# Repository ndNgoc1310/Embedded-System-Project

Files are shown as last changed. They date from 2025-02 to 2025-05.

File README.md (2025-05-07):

# ChronoSync – Embedded Digital Clock

**Course**: EE3427 Embedded Systems  
**Semester**: 242  
**University**: Ho Chi Minh City University of Technology  
**Group**: TT01 – Group 01  
**Members**: Nguyễn Duy Ngọc, Bùi Đình Trung Nam, Nguyễn Hùng Minh

---

## 📌 Overview

ChronoSync is a compact, low-power embedded digital clock system built on the STM32F103C8T6 microcontroller. It features:

- Real-time timekeeping with ±2 ppm accuracy (DS3231)
- E-Ink display for ultra-low power static UI
- Alarm scheduling (up to 10 configurable alarms)
- Button-based and Bluetooth-based configuration
- Mobile app interface built with MIT App Inventor
- Persistent EEPROM-based alarm storage

---

## 🧩 Project Objectives

- Integrate real-time hardware modules using I²C, SPI, UART
- Optimize for low-power and battery-operated design
- Provide physical and mobile-based time/alarm configuration
- Ensure modular firmware and maintainability
- Design a compact PCB with future 3D enclosure support

---

## ⚙️ System Features

### ✅ Implemented

- Real-time clock display and update every second
- Time and alarm configuration via 5 physical buttons
- View and edit alarm slots with ON/OFF toggle
- Bluetooth mobile app for time and alarm setting
- Alarm match detection and buzzer melody
- Power-efficient E-Ink display
- EEPROM alarm persistence across resets
- System option to clear all alarms

### 🚧 Pending/Partially Implemented

- Button long-press for continuous input adjustment
- Factory reset, display test mode
- Battery holder integration and battery percentage
- Real-time update and editing from mobile app
- Final enclosure (currently carton prototype)
- Display UI refinement

---

## 📐 Hardware Overview

| Component | Description |
|---|---|
| **MCU** | STM32F103C8T6 (ARM Cortex-M3, 72 MHz) |
| **RTC** | DS3231SN – I²C, high-precision timekeeping |
| **Display** | 2.9” Waveshare E-Ink display – SPI |
| **EEPROM** | AT24C64D – 64Kbit, I²C |
| **Bluetooth** | HC-05 module – UART |
| **Buttons** | 5 tactile buttons – short & long press detection  |
| **Buzzer** | 9x4.2mm, 80 dB with transistor driver |
| **Power** | Buck converter TPS54231 + AMS1117-3.3V regulator  |

---

## 📱 Mobile App

- Developed using **MIT App Inventor**
- Connects via **Bluetooth HC-05**
- Supports:
  - Time sync & setup
  - Alarm configuration (DoW or DoM modes)
  - Real-time communication with STM32

---

## 🛠️ Development Tools

- **Hardware**: Altium Designer, Oscilloscope, Multimeter
- **Firmware**: STM32CubeIDE, STM32CubeMX, ST-Link Utility
- **App**: MIT App Inventor
- **Version Control**: GitHub

---

## 📈 Performance Highlights

| Constraint | Status  | Description |
|---|---|---|
| C-1.1 ±3 ppm Accuracy| ✅ Met | DS3231 TCXO verified over 24 hrs |
| C-2.1 Data Retention | ✅ Met | EEPROM retains data post power-loss  |
| C-3.1 Input <30 ms | ✅ Met | Short press detected ~20–30 ms |
| C-5.1 Size ≤ 15x15x8cm| ✅ Met  | PCB and layout within limits |

*See report for unverified constraints.*

---

## 📁 Folder Structure

```bash
.
├── 1. Documents/                 # Figures, planning documents, technical references
├── 2. Hardware Design/           # Schematic and PCB layout files (Altium Designer project)
├── 3. Firmware Design/           # STM32CubeIDE project for embedded firmware
├── 4. Mobile Application Design/ # MIT App Inventor source files and exported .aia/.apk packages
├── 5. Report                     # # Final formatted report for submission, figures, and exported PDF
├── .vscode/                      # VSCode workspace settings
├── README.md                     # Project overview and documentation

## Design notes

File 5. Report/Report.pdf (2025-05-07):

VIETNAM NATIONAL UNIVERSITY – HO CHI MINH CITY

UNIVERSITY OF TECHNOLOGY

----o0o---

# PROJECT REPORT

## TOPIC:

# CHRONOSYNC –

# EMBEDDED DIGITAL CLOCK

Subject: | Embedded System
Subject code: | EE3427
Instructor: | MSc. Bui Quoc Bao
Semester: | 242
Class: | TT01
Group: | 01
Group’s member: Nguyễn Duy Ngọc | 2251036
Bùi Đình Trung Nam | 2251032
Nguyễn Hùng Minh | 2251030

Ho Chi Minh City, May 2025

### TASK TABLE

Name | ID | Task name | Contribution | Rating
Nguyễn Duy Ngọc | 2251036 | Firmware Design | 100% | Good
Bùi Đình Trung Nam | 2251032 | Mobile Application Design | 100% | Good
Nguyễn Hùng Minh | 2251030 | Hardware Design Firmware Design (E-Ink Display handler) | 100% | Good

### TABLE OF CONTENTS

A. INTRODUCTION

### 1. Background and Motivation

Embedded systems play a crucial role in modern digital devices, from consumer electronics to industrial automation. Among these applications, digital clocks represent a fundamental yet essential embedded system that requires precise timekeeping, efficient hardware-software interaction, and user-centric interface design. The development of such a system provides an excellent opportunity to explore real-world applications of microcontroller programming, peripheral interfacing, and power optimization.

The ChronoSync project was initiated as a comprehensive learning experience to integrate multiple aspects of embedded system design into a cohesive, functional product. The motivation behind this project is threefold:

- Practical Application of Embedded Knowledge: By designing a digital clock from scratch, the team is able to apply theoretical knowledge gained from coursework—including real-time constraints, interrupt-driven programming, and low-power techniques—into a tangible product.
- Exploration of Component-Level Integration: The project encourages hands-on experience with various hardware modules such as E-Ink displays, real-time clocks (DS3231SN), non-volatile memory (AT24C64D EEPROM), and Bluetooth modules (HC-05). This integration broadens the team's exposure to widely used industry components and communication protocols like I²C, SPI, and UART.
- Focus on Usability and Expandability: The inclusion of a mobile app interface using MIT App Inventor reflects the team’s emphasis on enhancing user interaction and accessibility. This wireless control interface allows users to configure alarms and time settings remotely, simulating real-world smart device functionality.

Through this project, the team not only aims to build a reliable embedded digital clock system, but also to gain a deeper understanding of multidisciplinary embedded design— ranging from circuit design and firmware development to user experience (UX) and mobile connectivity.

### 2. Project Objectives

The objective of this project is to design and implement a compact, low-power digital clock system – ChronoSync – based on the STM32F103C8T6 microcontroller. To achieve this, the project is divided into the following structured tasks:

- Task 1: Component Analysis and Communication Integration: Study the operating principles and technical specifications of key modules, including the E-Ink display, HC-05 Bluetooth module, DS3231SN real-time clock (RTC), AT24C64D EEPROM, and the STM32F103C8T6 microcontroller. Emphasis is placed on integrating these components using I²C, SPI, and UART protocols to ensure reliable communication between peripherals and the MCU.

- Task 2: Power Supply Design and Energy Management: Analyze the operation of boost converters and low-dropout regulators (LDOs) to design an efficient power supply. Explore strategies for reducing power consumption. Select appropriate components and calculate electrical parameters to ensure stability, safety, and long battery life.
- Task 3: Hardware Design and Enclosure Development: Design the complete schematic and PCB layout using Altium Designer, integrating all functional blocks such as the MCU, display, memory, and input interface. Fabricate the PCB and develop a custom 3D-printed enclosure that matches the board dimensions, protects components, and enhances usability and aesthetics.
- Task 4: System Integration and Functional Testing: Combine the hardware and firmware subsystems into a fully functional prototype. Perform iterative testing to validate feature operation, resolve integration issues, and ensure overall system stability under various conditions.
- Task 5: Performance Evaluation and Refinement: Evaluate the system in terms of timing accuracy, responsiveness, power efficiency, and user interface usability. Compare the results with the original specifications, identify limitations, and propose improvements or extensions for future development.
- Task 6: Mobile Application Development: Design and implement a companion mobile application using MIT App Inventor. The app communicates with the embedded system via Bluetooth, allowing users to configure time, set alarms, and send control commands wirelessly, thereby enhancing accessibility and interaction.

This comprehensive project not only demonstrates core embedded systems principles, but also highlights cross-platform integration, real-time processing, and power-aware design in a complete, user-friendly product.

### 3. System Specifications 3.1. Functional Requirements

FR-1: The system must have time display functionality.

- FR-1.1: The system shall display the current time.
- FR-1.2: The system shall update the displayed time once every second.
- FR-1.3: The displayed format shall include hour, minute, day of week (DoW), date of month (DoM), month, and year in the format HH:MM, DD:MM:YY.
- FR-1.4: The system shall retain real-time data across power loss.

FR-2: The system must be able to store alarms.

- FR-2.1: The system shall allow users to configure up to 10 alarms.
- FR-2.2: Each alarm shall consist of: hour, minute, second, DoW or DoM, alarm mode (DoW/DoM/unused), and an ON/OFF flag.

- FR-2.3: The system shall compare current time and stored alarms every second to detect matches.
- FR-2.4: Upon matching, the system shall activate a buzzer and show the alarm status on screen.
- FR-2.5: Alarm configurations shall be retained across power cycles.

FR-3: The system must allow time and alarm configuration via physical buttons.

- FR-3.1: The buttons shall support incrementing, decrementing, and navigating between configuration fields.
- FR-3.2: The system shall support both short press and long press detection to accelerate user input.

FR-4: The system must allow alarm review and editing.

- FR-4.1: The system shall allow users to browse existing alarms by slot index.
- FR-4.2: The system shall allow users to toggle an alarm’s ON/OFF state while reviewing.
- FR-4.3: The system shall support editing a selected alarm.

FR-5: The system must allow time and alarm configuration wirelessly.

- FR-5.1: The system shall support a mobile application for wireless configuration.
- FR-5.2: The system shall communicate with the app via bluetooth.
- FR-5.3: The app shall support time synchronization and alarm setup from a smartphone.

FR-6: The system shall provide system additional features.

- FR-6.1: System Options shall include:
- FR-6.1.1: Clear all alarms.
- FR-6.1.2: Perform factory reset.
- FR-6.1.3: Run display test pattern.
- FR-6.1.4: Show distributor information.

FR-7: The device must be compact, portable, and physically robust.

- FR-7.1: The device shall have a case made of Mica or ABS plastic for lightweight and durable protection.

FR-8: The device must support low power consumption and extended battery operation.

- FR-8.1: The device shall include an E-Ink display to minimize power consumption.
- FR-8.2: The device shall be powered by a rechargeable lithium-ion battery to support long-duration operation.
- FR-8.3: The system shall display the remaining battery level in percentage on the screen.

### 3.2. Constraints and Performance Requirements

C-1: Timing and Accuracy

- C-1.1: The system shall ensure time deviation is less than ±3 ppm at room temperature.
- C-1.2: Alarm matching logic shall be executed within 50 ms per main loop iteration.
- C-1.3: On power loss, the system shall maintain accurate real time for at least 30 days.

C-2: Alarm Storage

- C-2.1: The system must retain all alarm data across power loss.
- C-2.2: Total memory usage for alarm storage shall not exceed 50 bytes.
- C-2.3: Storage read/write operations shall complete in less than 10 ms.

C-3: Input Responsiveness

- C-3.1: A short button press shall be detected with latency under 30 ms.
- C-3.2: A long button press shall be registered after holding the button for 600 ms.
- C-3.3: Button debouncing shall ensure fewer than 1 false trigger per 100 presses.

C-4: Power and Energy Constraints

- C-4.1: The system shall operate on four 2000 mAh, 3V lithium-ion batteries.
- C-4.2: The system shall function for at least 90 days on a full charge in idle conditions.
- C-4.3: The system shall consume less than 3 mW during typical operation.
- C-4.3.1: The system shall perform periodic operations (e.g., real-time updates, alarm checks, battery polling) once per second to minimize power usage.
- C-4.3.2: The display shall consume no more than 0.02 mW in all operating modes.
- C-4.3.2.1: The display refresh rate shall be limited to 1 Hz when displaying real time, and shall only refresh on value changes in other modes.

C-5: Physical Dimensions

- C-5.1: The overall device dimensions shall not exceed 15 cm × 15 cm × 8 cm.
- C-5.2: The total weight of the device shall be less than 300 g.

B. MATERIALS AND METHODS

### 1. List of components

No. | Component | Quantity | Function
1 | DC5521 Power Jack 1A | 1 | Standard DC input for external power supply or charger.
2 | SS54 Schottky Diode 5A 40V | 1 | Drops the input voltage before the inductor in the buck converter.
3 | SMD CDRH127 Inductor 68µH 3.2A | 1 | Enables current regulation and energy storage in the buck converter circuit.
4 | TPS54231DR Buck Converter | 1 | Steps down 12V input to lower voltages (5V) efficiently for system operation.
5 | AMS1117 Regulator 3.3V 1A | 1 | Provides a stable 3.3V output from the 5V rail to power the STM32 and other 3.3V devices.
6 | SMD Capacitor 100µF | 4 | Used for power decoupling and smoothing voltage across supply rails.
7 | TAJC476K016RNJ 2312 Tantalum Capacitor 47uF | 2 | Acts as a local bypass capacitor to stabilize voltage and reduce noise near sensitive ICs.
8 | STM32F103C8T6 Microcontroller | 1 | Main controller managing timekeeping, UI, display, and communication.
9 | SMD HC49-S Crystal Oscillator 8MHz | 1 | Provides system clock for STM32 core.
10 | FC-135 3215 Crystal 32.768kHz | 1 | Provides a low-frequency clock source option for the STM32 core.
11 | DS3231SN RTC Module | 1 | High-accuracy real-time clock with backup capability.
12 | AT24C64D-SSHM-T EEPROM 64Kbit | 1 | Stores alarm settings and user configuration permanently.
13 | Tactile Buttons 12 x 12 mm | 5 | Buttons for user input, each with short/long press detection.
14 | SMD 0805 Resistor 10kΩ | 5 | Pull-up/down resistors for buttons and logic-level conditioning.
15 | SMD 0805 Capacitor 100nF | 5 | Used for hardware debouncing of push buttons by filtering out signal noise and eliminating false triggers.
16 | Waveshare E-Ink Display 2.9" | 1 | Low-power, high-contrast display for time and status.
17 | SMD 0805 LED | 3 | Status indicators for 5V rail, 3.3V rail, and the PC13 GPIO pin.
18 | 9056-TS Buzzer 80dB | 1 | Emits sound when an alarm is triggered.
19 | MMBT2222A NPN Transistor 40V 0.6A | 1 | Used as a low-side switch to drive current to the buzzer.

20 | HC-05 Bluetooth Module | 1 | Enables wireless setup and control via smartphone app.
21 | 2-Pin Female XH2.54 Cable | 5 | Used to easily connect buttons to the PCB.
22 | 2-Pin Male Header XH2.54 | 5 | Mates with XH2.54 cables to provide sturdy, pluggable connections for signals on the PCB.
23 | 8-Pin Male Header XH2.54 | 1 | Used for display signal interfaces (SPI).
24 | 8-Pin Female XH2.54 Cable | 1 | Paired with XH2.54 headers for SPI interface.

### 2. Selection Criteria and Justifications

The components selected for the ChronoSync embedded digital clock were chosen based on critical engineering criteria: functional reliability, power efficiency, cost-effectiveness, compactness, and ease of integration. Each category below outlines the rationale for component selection in terms of system requirements and performance optimization.

### 2.1. Microcontroller Unit (MCU)

Component: STM32F103C8T6 (ARM Cortex-M3, 72MHz)

Justification:

- Offers sufficient computational power to handle real-time clock tracking, alarm scheduling, display control, and Bluetooth communication.
- Provides a wide range of peripheral interfaces: I²C (RTC, EEPROM), SPI (E-Ink), UART (Bluetooth).
- Low power consumption and supported by STM32CubeIDE and HAL drivers for efficient firmware development.

### 2.2. Power Supply

Components: TPS54231 Buck Converter, AMS1117-3.3V Regulator, SS54 Schottky Diode, CDRH127 Inductor, 100µF Electrolytic Capacitors, TAJC476K016RNJ 47µF Tantalum Capacitors

Justification:

- TPS54231 is a high-efficiency step-down converter capable of supplying 2A output current, ideal for converting 12V DC input to 5V with minimal power loss.
- AMS1117-3.3V linear regulator provides a stable 3.3V output necessary for core system components such as the STM32, RTC, EEPROM, and Bluetooth module.
- The SS54 Schottky diode ensures low forward voltage drop and fast switching, improving conversion efficiency and protecting against reverse current.

- The SMD CDRH127 inductor (68µH, 3.2A) stabilizes current flow through the buck converter, reducing voltage ripple and electromagnetic interference.
- Electrolytic and ceramic SMD capacitors are placed on power lines to suppress voltage spikes, smooth output, and reduce noise coupling.
- TAJC476K016RNJ Tantalum capacitors (47µF) act as bypass and filtering elements, ensuring voltage stability during transient loads and providing local energy storage near the regulators.

### 2.3. Oscillators and Timing Components

Component: 8MHz Crystal (STM32 system clock), 32.768kHz FC-135 Crystal (RTC backup)

Justification:

- 8MHz crystal ensures stable and accurate operation of the STM32 MCU.
- 32.768kHz crystal enhances timekeeping accuracy and is compatible with low-power RTC operation.

### 2.4. Display System

Component: 2.9-inch Waveshare E-Ink Display

Justification:

- Power-efficient as it only draws current during screen refresh.
- Excellent visibility in ambient light; ideal for static time display.
- Communicates over SPI with STM32, reducing pin usage and enabling fast updates.

### 2.5. Timekeeping

Component: DS3231SN RTC Module

Justification:

- Temperature-compensated crystal oscillator for ± 2 ppm accuracy.
- Maintains real-time across power cycles using coin-cell backup.
- Communicates over I²C with minimal code overhead.

### 2.6. Alarm Storage

Component: AT24C64D EEPROM (64Kbit)

Justification:

- Non-volatile memory ensures alarm data persists through power loss.
- Fast I²C communication with write cycles well within application constraints.

- 64 Kbit provides ample space for storing up to 10 alarm configurations, along with headroom for future feature upgrades or additional system data.

### 2.7. User Interface – Buttons and Indicators

Component: Tactile Push Buttons (12×12mm), SMD LED 0805 (Power Indicators), 100nF Capacitors, SMD 0805 Resistor 10kΩ

Justification:

- Buttons provide a reliable interface for configuration and navigation. Their size ensures usability.
- Dual short/long press recognition expands functionality without additional components.
- SMD LEDs provide visual feedback for system states (5V, 3.3V, heartbeat via PC13 pin).
- 100nF ceramic capacitors and 10 kΩ resistors are used for hardware debouncing of button signals.

### 2.8. Audio and Output Control

Components: 9x4.2mm 80dB Buzzer, MMBT2222A NPN Transistor

Justification:

- The buzzer provides audible feedback for alarm activation.
- The MMBT2222A acts as a current driver, switching the buzzer on/off through a GPIO pin safely without overloading the MCU.

### 2.9. Wireless Communication

Component: HC-05 Bluetooth Module

Justification:

- Enables wireless communication with a custom mobile app developed using MIT App Inventor.
- UART-based interface simplifies integration with STM32.
- Supports bidirectional control of time and alarms from mobile devices.

2.10.Connectors and Wiring

Component: XH2.54 Bus Cables (2-pin and 8-pin), XHB-2A Connectors

Justification:

- These connectors simplify module interconnection and allow easy debugging or module replacement.

- Standardized 2.54mm pitch ensures compatibility with PCB and peripheral modules.

### 3. Development Tools

The development of the ChronoSync embedded system leverages a comprehensive suite of software and hardware tools for circuit design, firmware development, simulation, and debugging. Each tool was selected based on compatibility with the STM32 platform, support for industry standards, and community resources.

### 3.1. Hardware Development Tools

- Altium Designer
- Purpose: Used for schematic capture and PCB layout design.
- Justification: Professional-grade EDA tool with precise control over routing, layout constraints, and multi-layer design, enabling high-reliability circuit boards suitable for compact embedded systems.
- Soldering Station & Solderer
- Purpose: Manual soldering of surface-mount and through-hole components.
- Justification: Required for assembling the custom-designed PCB, especially for SMD parts like STM32F103C8T6 and EEPROM.
- Digital Multimeter & Oscilloscope
- Purpose: Testing power lines, signal integrity, and time-domain behavior of waveforms (e.g., SPI, UART, PWM for buzzer).
- Justification: Essential for debugging hardware-level faults and verifying timing constraints.

### 3.2. Firmware and Embedded Software Tools

- STM32CubeIDE
- Purpose: Main integrated development environment (IDE) for writing, compiling, and debugging C code on the STM32 platform.
- Justification: Official STMicroelectronics toolchain supporting STM32F1 series with STM32CubeMX integration, HAL drivers, and peripheral configuration GUI.
- STM32CubeMX
- Purpose: Peripheral and clock configuration tool with automatic code generation.
- Justification: Simplifies hardware abstraction and generates consistent initialization code, reducing development errors.
- ST-Link Utility/OpenOCD
- Purpose: Flashing and debugging firmware via ST-Link.

- Justification: Enables low-level programming and real-time debugging with breakpoint and register inspection capability.

### 3.3. Mobile Interface Tools

- MIT App Inventor
- Purpose: Rapid development of the companion mobile app.
- Justification: Offers a block-based visual programming environment suitable for prototyping Bluetooth-based UI without deep Android development expertise.

### 3.4. Version Control and Documentation

- GitHub
- Purpose: Source code management, issue tracking, and collaboration.
- Justification: Facilitates transparent teamwork and history tracking. All
design | files, | firmware, | and | documents | are | hosted | at:
https://github.com/ndNgoc1310/Embedded-System-Project
- Microsoft Word
- Purpose: Report writing and formatting.
- Justification: Allows structured documentation of the development process and output files suitable for academic and professional submission.

### 4. Programming and Debugging Methodology 4.1. Programming Structure and Naming Convention

The firmware is developed using the C programming language, structured into modular units with clear separation between application logic and low-level hardware interaction. This is achieved through a multi-layered architecture, including:

- Application Layer: Handles system state logic and mode transitions.
- Middleware Layer: Manages data encoding/decoding, EEPROM access, and RTC time parsing.
- Driver Layer: Interfaces with external peripherals such as the RTC (DS3231), EEPROM (24C32), buttons, buzzer, and E-Ink display.

All functions and variables strictly follow a unified naming convention. Prefixes are assigned according to module ownership, ensuring clarity and preventing namespace collisions. This convention included:

- camelCase for local variables,
- lowercase_with_underscores for global variables and struct members,
- Upper_Camel_Snake_Case for function names, and
- ALL_CAPS_WITH_UNDERSCORES for macros and constants.

This structured organization and naming standard promote code readability, maintainability, and ease of collaboration among team members.

### 4.2. Debugging Strategy

A disciplined debugging approach was followed throughout development. Using STM32CubeIDE, the following techniques were employed:

- Live Expressions Monitoring: Temporary and persistent state variables were tracked in real time to understand logic flow and diagnose anomalies.
- Breakpoints and Step Execution: Specific sections of code were paused and stepped through to trace faults and validate assumptions.
- Hardware-in-the-Loop Testing: Each update was tested on real hardware to verify actual peripheral behavior and detect timing or synchronization issues not visible in simulation.
- Modular Testing: Subsystems (e.g., EEPROM access, time sync, buzzer logic) were individually validated before full integration.
This methodology ensured high firmware reliability, fast bug localization, and efficient conflict resolution across hardware and software boundaries.

C. SYSTEM DESIGN

### 1. System Architecture Overview

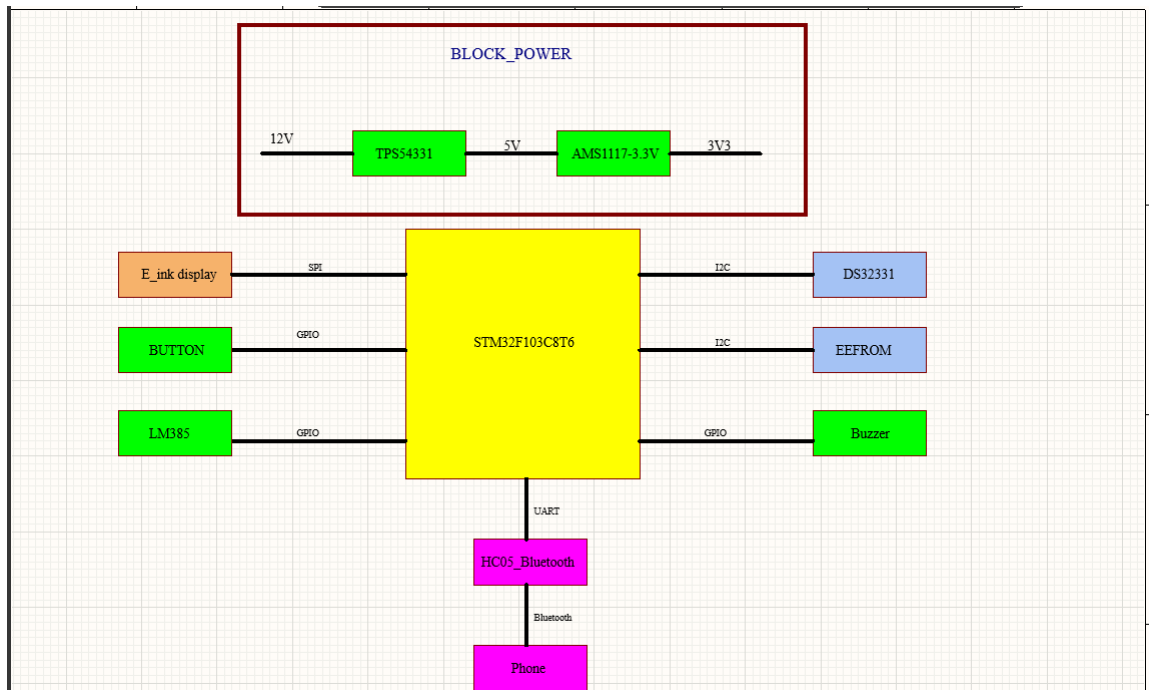
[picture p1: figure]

Figure 1. System overview
Phone
- Task: Communicate with the system via Bluetooth connection.
- Function: User interaction.

HC05 BLE (Bluetooth Low Energy)

- Task: Wireless connection with the phone via Bluetooth.
- Function:
- Receive signals from the phone (e.g., time adjustments).
- Transmit data to the STM32 microcontroller via UART.
- Bidirectional communication between the phone and MCU to update clock status or adjust time

IC TPS54331

- Task: Step down the voltage from 12V to 5V.
- Function: Step down the voltage to 5V to supply BLE and to step down 3V3 through the AMS1117.

IC AMS1117

- Task: Step down the voltage from 5V to 3.3V.
- Function: Supply voltage to STM32F103C8T6, E-ink-display and other devices.

STM32F103C8T6 Microcontroller

- Task: Control the entire system’s operation.

- Function:
- Process data received from the BLE module
- Control the E-Ink display to show time.
- Process the signal from the buttons.
- Read and write the data from the DS3231 and EEFROOM
- Manage power from the boost, buck converters, and backup battery. IC DS3231
- Task: Store the data of time.
- Function: Read and write the time data.

EEFROOM

- Task: Read and store data.
- Function: To store the data alarm.

IC LM385

- Task: The op amp to amplified the current.
- Function: Like the buffer to measure the voltage.

Buzzer

- Task: Generate audible alerts or notifications in response to specific events or conditions within the system.
- Function: Notify the alarm.

E-ink display.

- Task: Display the information for the users.
- Function: Display time and setting.

### 2. Hardware Design

a) Block diagram

Power supply

- In accordance with the design requirements, the product's power consumption should be minimized. Therefore, the team has decided to use the TPS54331 IC (buck DC converter) to step down the voltage to 5V, followed by the ASM1117 to further step down to 3.3V.
- Additionally, the power input will have two voltage sources: one from the adapter and another from the battery.

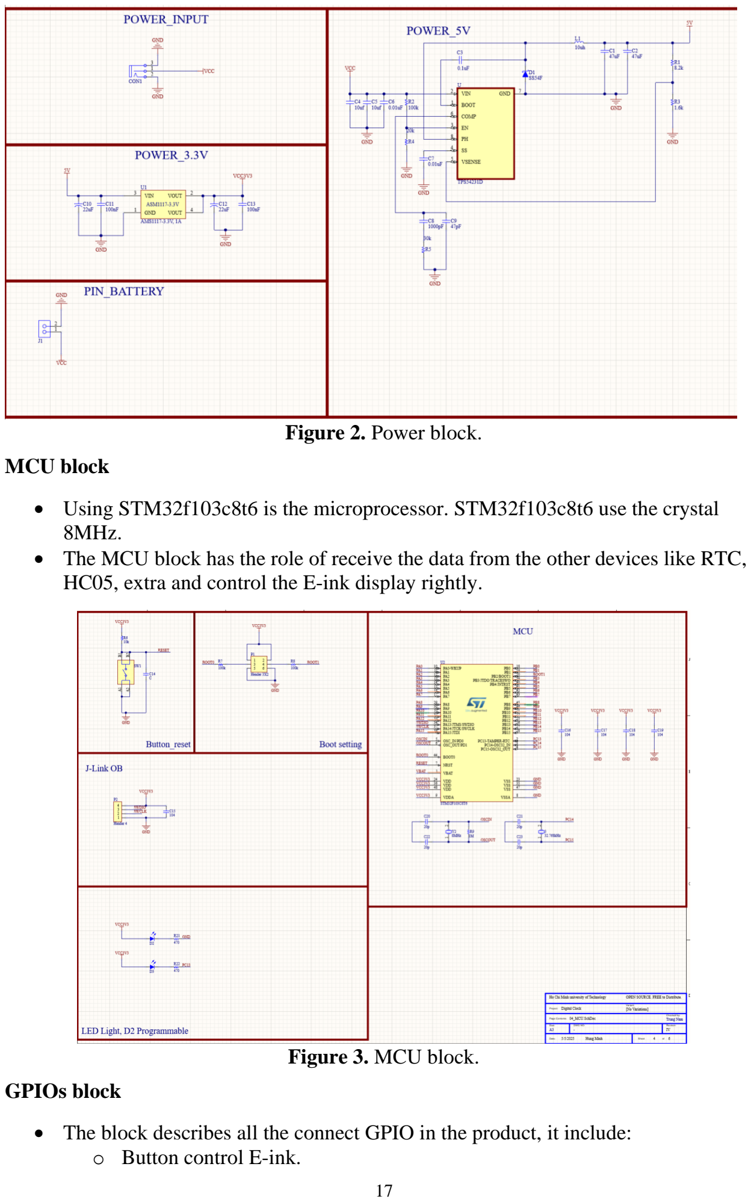
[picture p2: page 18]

Figure 2. Power block.

MCU block

- Using STM32f103c8t6 is the microprocessor. STM32f103c8t6 use the crystal 8MHz.
- The MCU block has the role of receive the data from the other devices like RTC, HC05, extra and control the E-ink display rightly.

Figure 3. MCU block.

GPIOs block

- The block describes all the connect GPIO in the product, it include:
- Button control E-ink.

- The IC LM385 to measure the Pin battery.
- The GPIO to control the buzzer.

Figure 4. GPIOs block.

Communication Protocols block

The block describes all the connect of protocol in the product:
- The EEFROM will be used by AT24C family and we will implement through the I2C. The same with RTC DS32331 is transferred the data through the I2C.
- The data of module HC-05 will be transmitted by UART while E-ink is used SPI protocol.

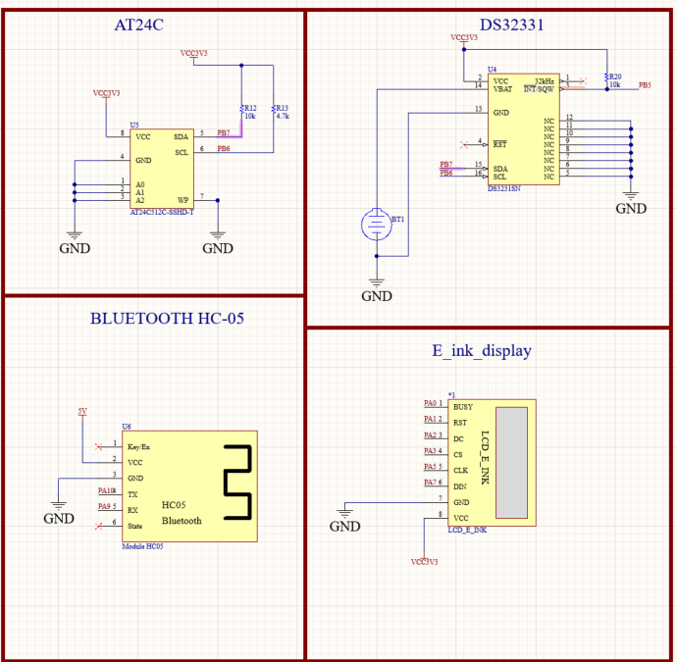
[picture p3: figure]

Figure 5. Communication Protocol block.

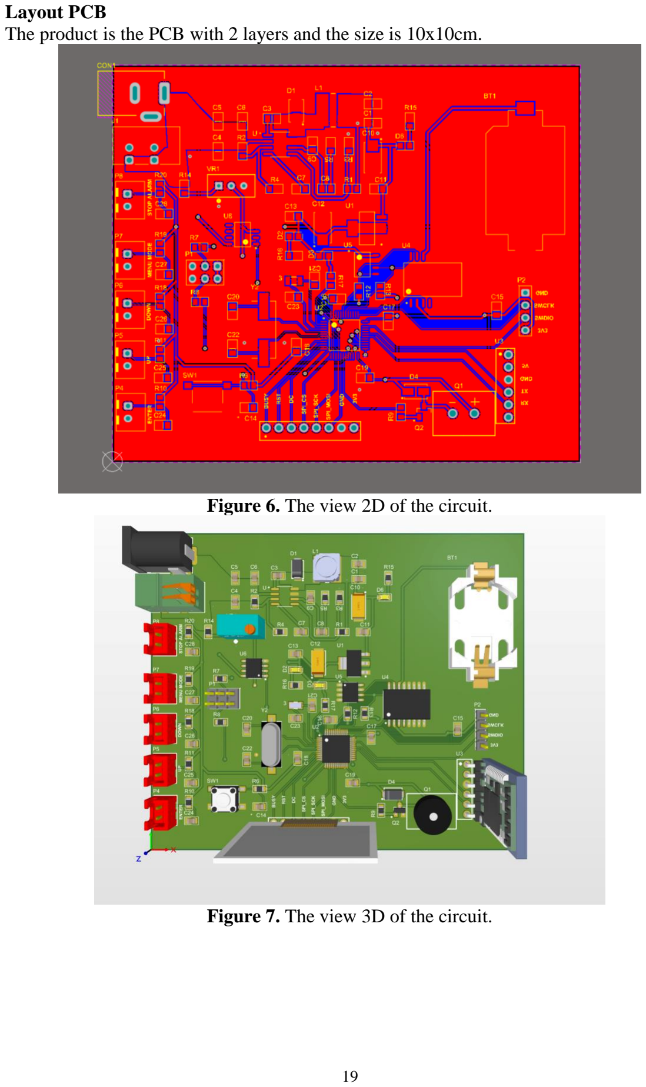
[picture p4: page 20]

Layout PCB
The product is the PCB with 2 layers and the size is 10x10cm.

Figure 6. The view 2D of the circuit.

Figure 7. The view 3D of the circuit.

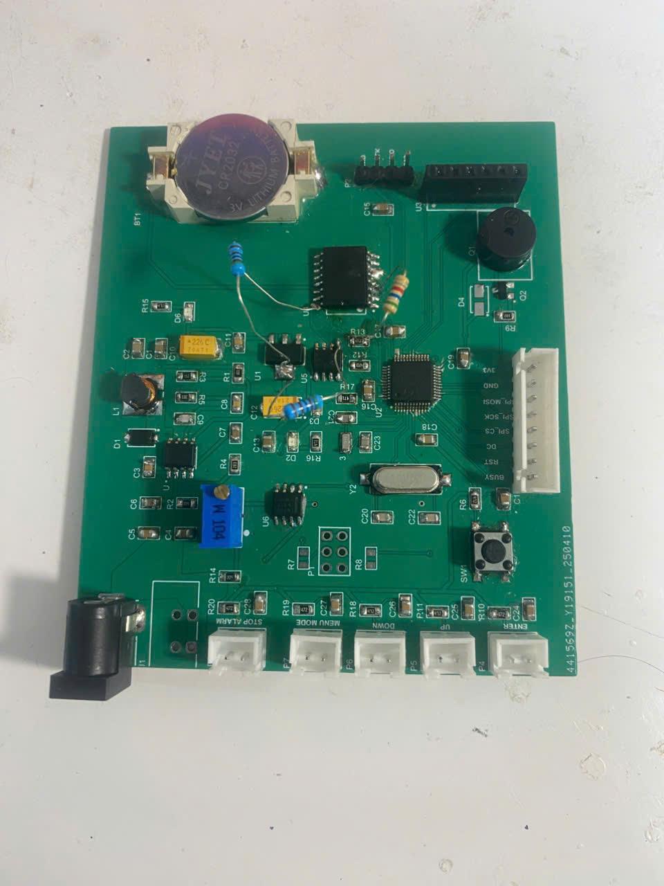
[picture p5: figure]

Figure 8. The view of the circuit.

### 3. Firmware Design

a) Requirement software
- Ability to process real-time signals ensuring the accuracy of real time.
- Users can adjust the time via Bluetooth: allowing users to easily adjust the time remotely.
- Can store time data when replacing the battery: limiting the need for users to adjust the time each time the battery is replaced.pin.
b) Flow chart:
- The flow chart will be divided into 3 parts:
- The first part is about the default mode. It will display the data read from the RTC and check the alarm.
- The second part is the flow chart of the system options choosing mode.
- The third part is the flow chart of controlling button.
- Default mode:

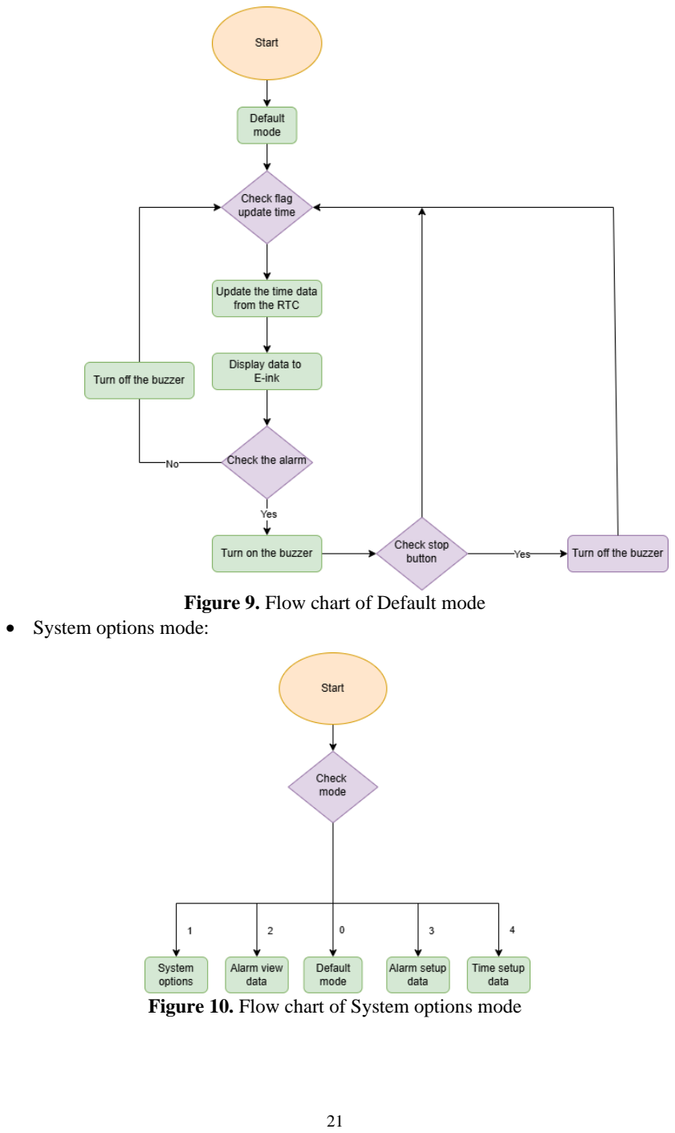
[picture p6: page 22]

Figure 9. Flow chart of Default mode
- System options mode:

Figure 10. Flow chart of System options mode

- Button setting:

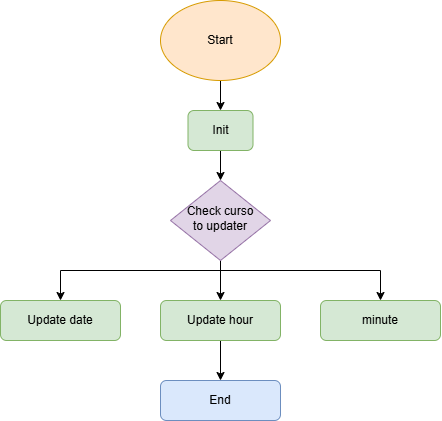
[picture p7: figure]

Figure 11. Flow chart of Button setting mode

### 4. Mobile Application Design

a) Introduction to MIT App Inventor
- To enhance user interaction and increase system flexibility, the ChronoSync embedded digital clock integrates a custom-built Android application developed using MIT App Inventor. This mobile app provides a wireless interface for adjusting both the time and alarms of the clock via Bluetooth communication, eliminating the need for manual configuration through physical buttons.
- The integration of the MIT App serves several important purposes in the system. Firstly, it improves user convenience, allowing real-time configuration of the clock from a distance without the need to physically access the hardware. Secondly, it enables multi-mode interaction, with distinct features such as time adjustment and flexible alarm scheduling for both weekly and monthly routines. Lastly, it demonstrates the practicality of combining embedded hardware with mobile software to build a more modern and responsive embedded system.
- Using MIT App Inventor brings notable advantages:
- Rapid development with a visual programming environment
- Cross-platform compatibility for Android devices
- Ease of integration with Bluetooth modules like HC-05
- User-friendly interface design without advanced coding

- In the ChronoSync project, the MIT App plays a crucial role as the primary interface between the user and the embedded clock system. It allows seamless communication over Bluetooth, enabling users to manage essential clock settings efficiently and intuitively.
b) User interface and modes

MIT App Inventor let user define the interface of the app and It’s functions through blocks.

Figure 11. Designer mode of MIT App Inventor

Figure 12. Blocks mode of MIT App Inventor Screen 1: Menu

Screen 1 is the first screen and the default screen that will automatically appear when we open the app. In this screen, we are free to choose what to do with our clock through 3 buttons:
- "Update Time and Date"
- "Update Alarms in Week"

- "Update Alarms in Month"

In Designer mode, we will see 3 buttons appear on the screen like the figure below:

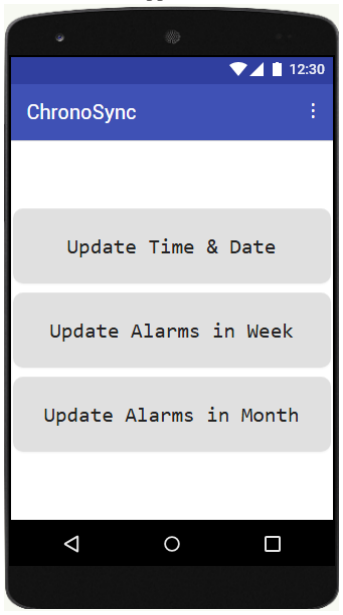
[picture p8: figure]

Figure 13. Screen 1
In the Blocks mode, We can observe the function of each buttons:

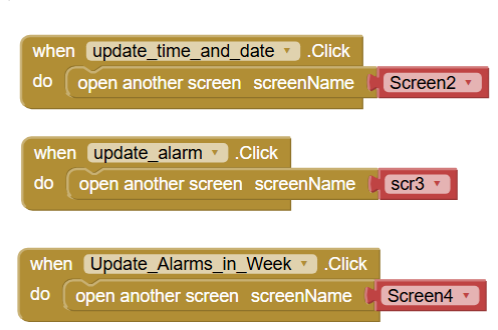
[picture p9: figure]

Figure 14. Blocks functions of Screen 1 For each buttons, they will lead us to others screen according to their functions. In this screen, the app is staying in Mode 0 (Idle Mode): Do nothing.

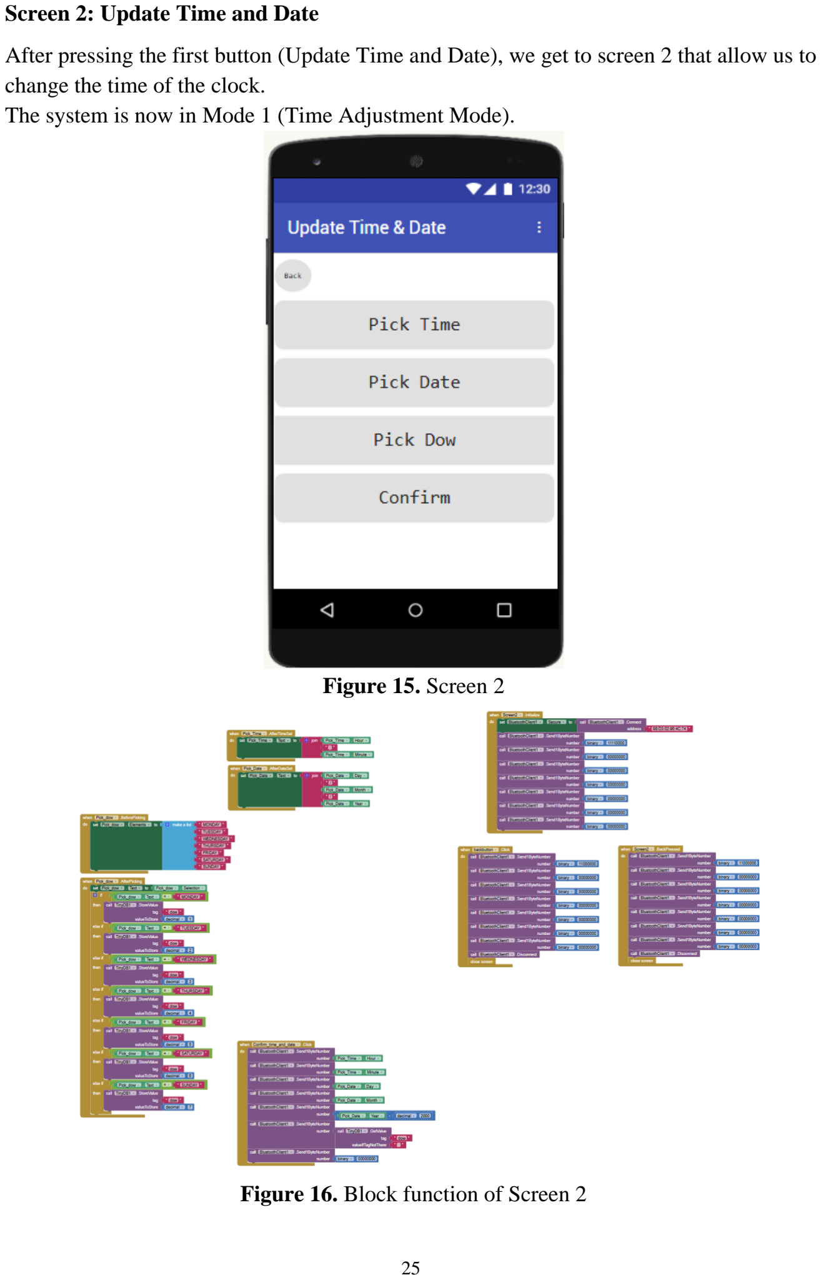
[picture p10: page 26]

Screen 2: Update Time and Date

After pressing the first button (Update Time and Date), we get to screen 2 that allow us to change the time of the clock.
The system is now in Mode 1 (Time Adjustment Mode).

Figure 15. Screen 2

Figure 16. Block function of Screen 2

In this mode, we can change time, date, day of the week and then press the confirm button to admit the adjustment to the clock.

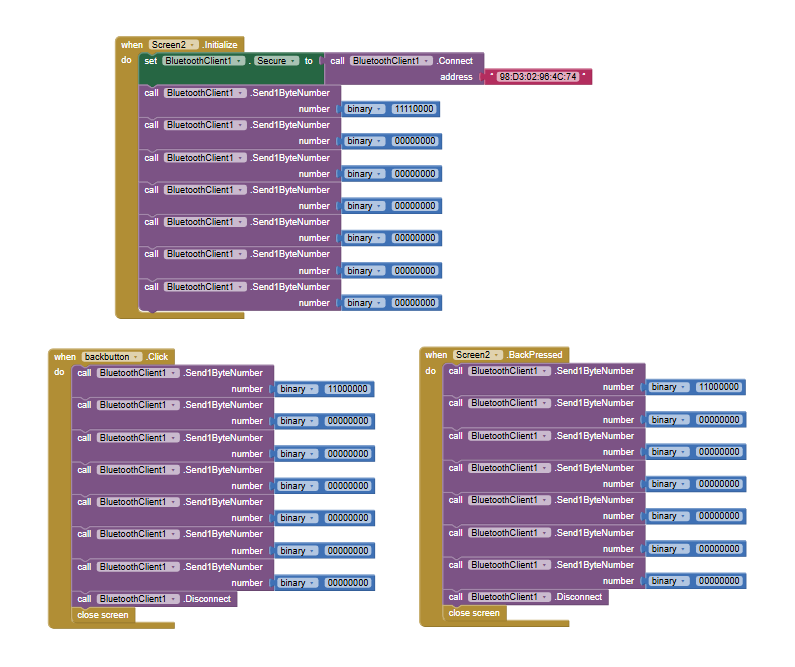
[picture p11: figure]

Figure 17. Initializing block and ending blocks of Screen 2 When the screen 2 initialize, the app will automatically connect to HC05 through address 98:D3:02:96:4C:74. After that, it will send 7 byte data (F0-00-00-00-00-00-00) to STM32 to announce that we’re in mode 1. The first byte is not only for hour data but for mode data too. Only when we press the back button or back press, STM32 will receive data (C0-00-00-00-00-00-00) that let it escape mode 1 to turn back to mode 0.

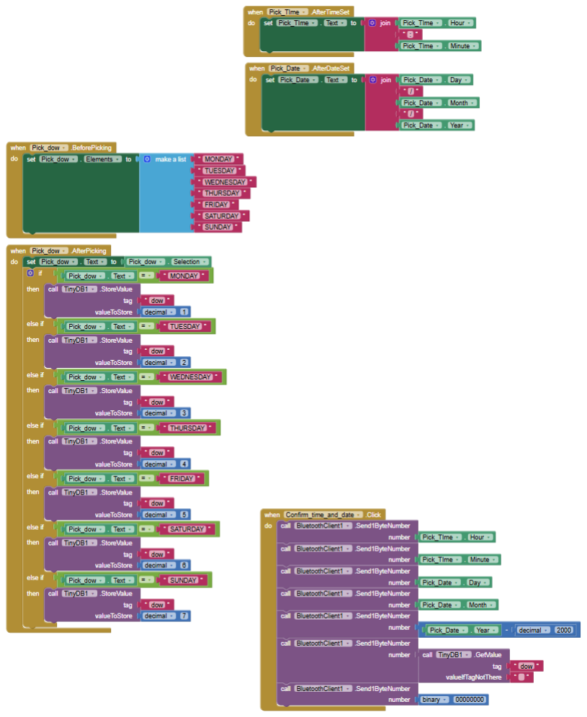
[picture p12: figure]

Figure 18. Function blocks of Screen 2 After set the time and date button, they will display the value that we chose.
For day of the week, we will choose from a list of day (Monday to Sunday). After picking, it will show our option on the screen and also save the value of dow value as it’s equivalent number. (1-Monday, 2-Tuesday, etc).
When we press the confirm button, all the data of time and date will be sent to STM32 via Bluetooth.
Note that data of the year have to minus for 2000 as it’s too big to fit in 1 byte.
Screen 3: Update Alarms in Month

After pressing the second button (Update Alarms in Month), we get to screen 3 that allow us to change the alarms of the clock in date mode.
The system is now in Mode 2 (Alarms Adjustment Mode).

Figure 19. Screen 3

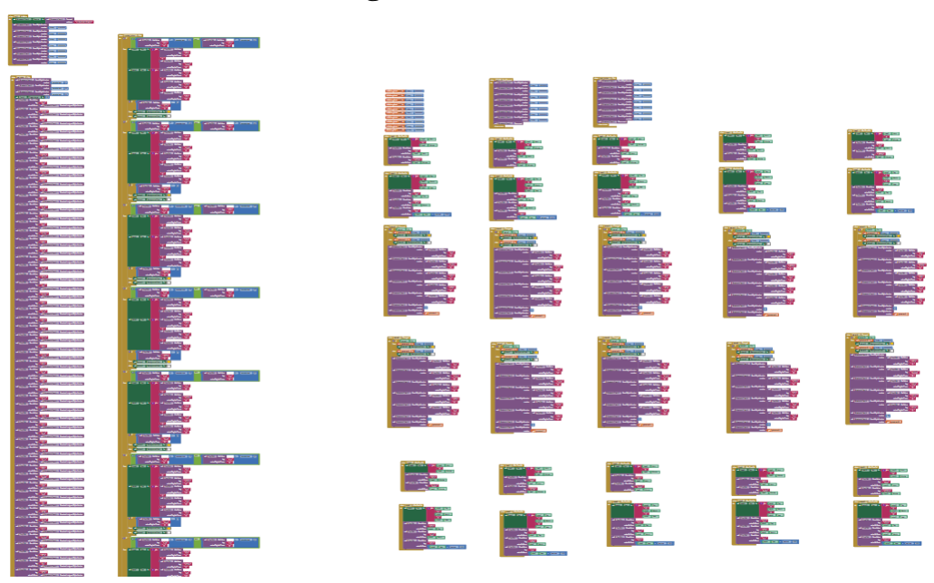
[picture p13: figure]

Figure 20. Blocks of Screen 3 In this mode we can adjust and set the alarms of the clock in detail of time and date.

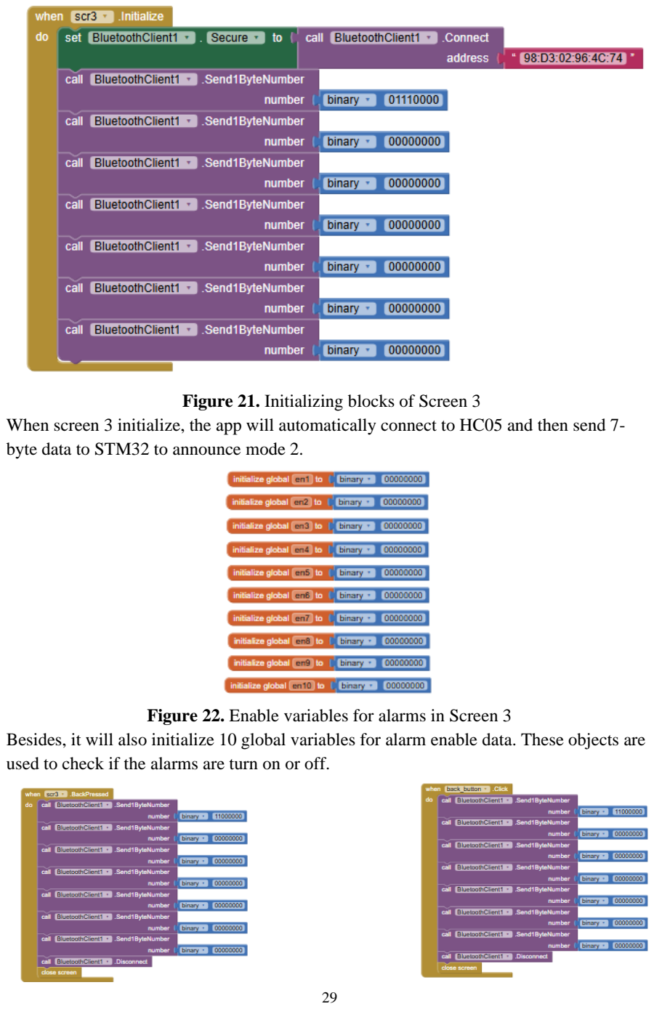
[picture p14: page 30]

Figure 21. Initializing blocks of Screen 3 When screen 3 initialize, the app will automatically connect to HC05 and then send 7-byte data to STM32 to announce mode 2.

Figure 22. Enable variables for alarms in Screen 3 Besides, it will also initialize 10 global variables for alarm enable data. These objects are used to check if the alarms are turn on or off.

Figure 23. Outing blocks of Screen 3 Same as mode 1, when we press back button or back press, it will send data to let system turn back to mode 0 and then close the current screen.

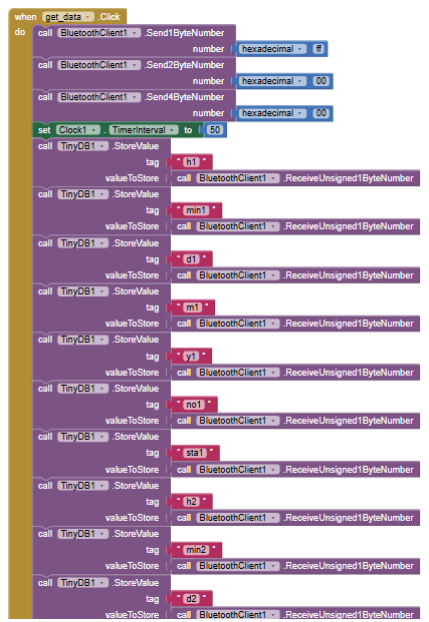
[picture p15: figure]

Figure 24. get_data blocks of Screen 3 This get data button is used to receive all 10 alarms data in STM32 and store them all in those tag. For each alarm, there will be 7 tags: h (hour), min (minute), d (day), m (month), y (year), no (# of the alarm), sta (status of the alarm).
Before we do all that, the app will send data to request STM32 to send data and then wait 50ms to stabilize the system.

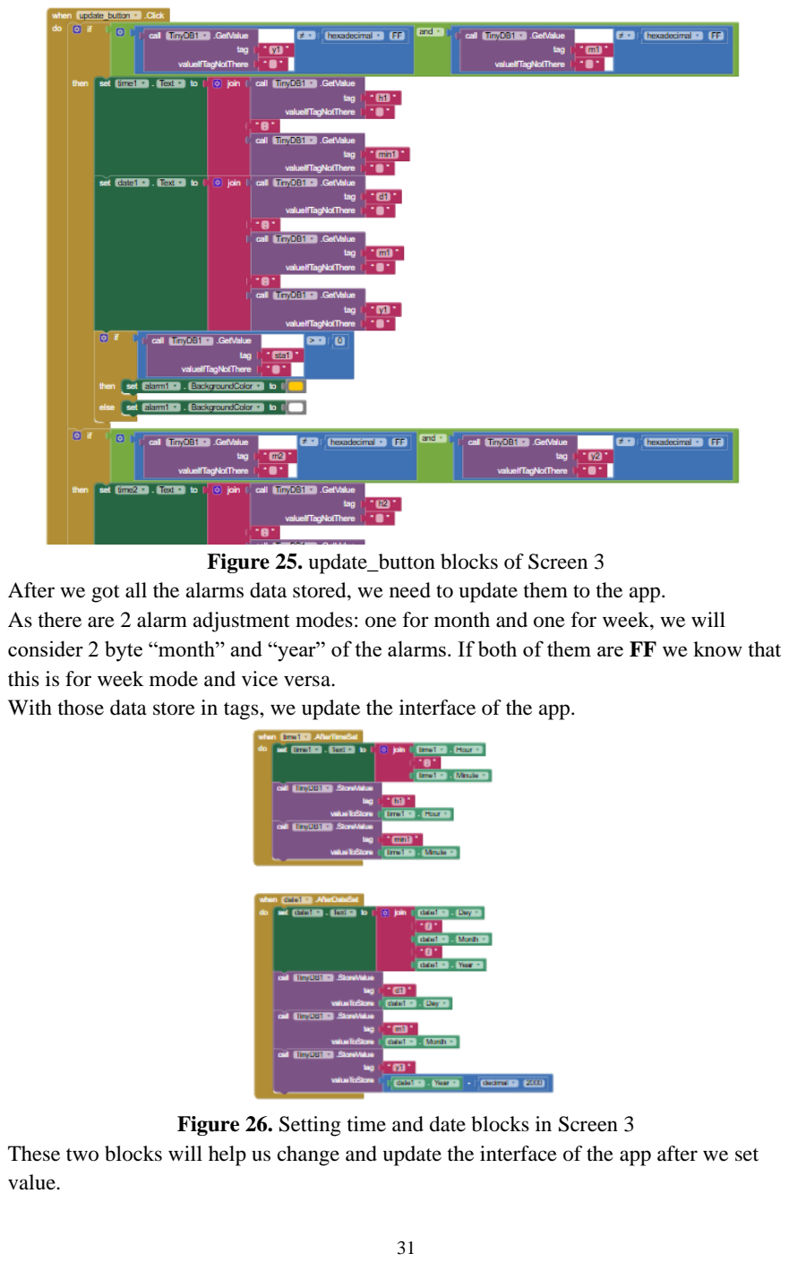
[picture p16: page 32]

Figure 25. update_button blocks of Screen 3 After we got all the alarms data stored, we need to update them to the app.
As there are 2 alarm adjustment modes: one for month and one for week, we will consider 2 byte “month” and “year” of the alarms. If both of them are FF we know that this is for week mode and vice versa.
With those data store in tags, we update the interface of the app.

Figure 26. Setting time and date blocks in Screen 3 These two blocks will help us change and update the interface of the app after we set value.

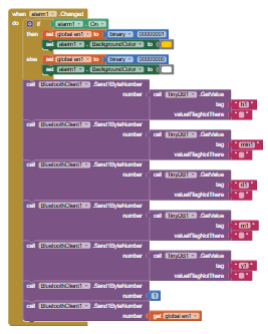
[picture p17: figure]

Figure 27. Sending data in Screen 3 To send data to the STM32, we toggle the switch called alarm to send all the data. Screen 4: Update Alarms in Week

After pressing the third button (Update Alarms in Week), we get to screen 4 that allow us to change the alarms of the clock in week mode.
The system is now in Mode 2 (Alarms Adjustment Mode).

Figure 28. Screen 4

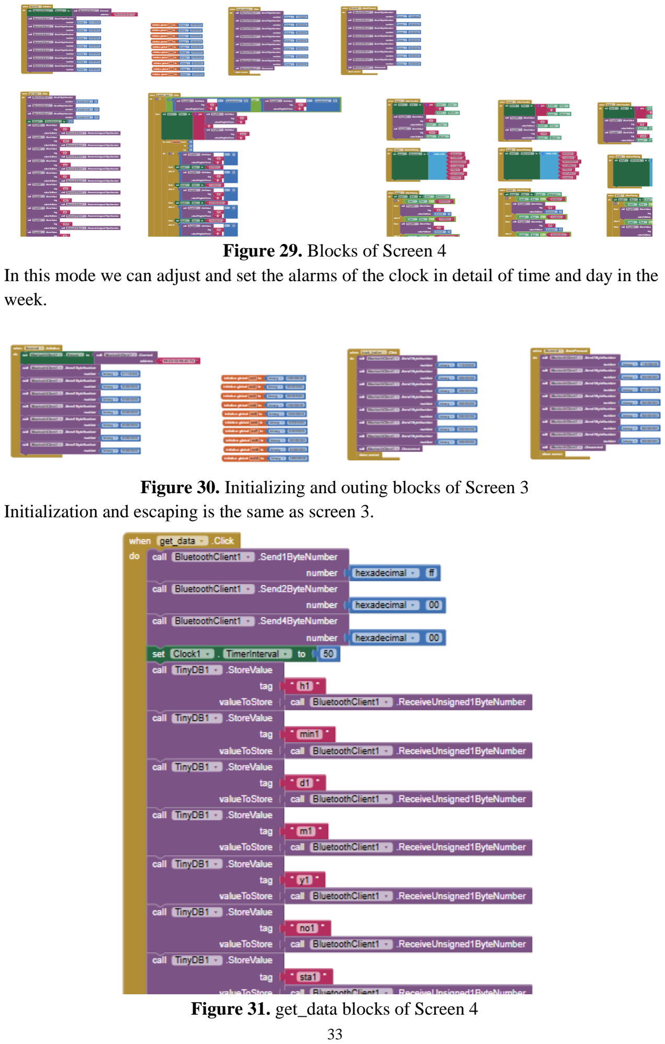
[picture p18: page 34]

Figure 29. Blocks of Screen 4 In this mode we can adjust and set the alarms of the clock in detail of time and day in the week.

Figure 30. Initializing and outing blocks of Screen 3 Initialization and escaping is the same as screen 3.

Figure 31. get_data blocks of Screen 4

Get data function is also same as the previous screen.

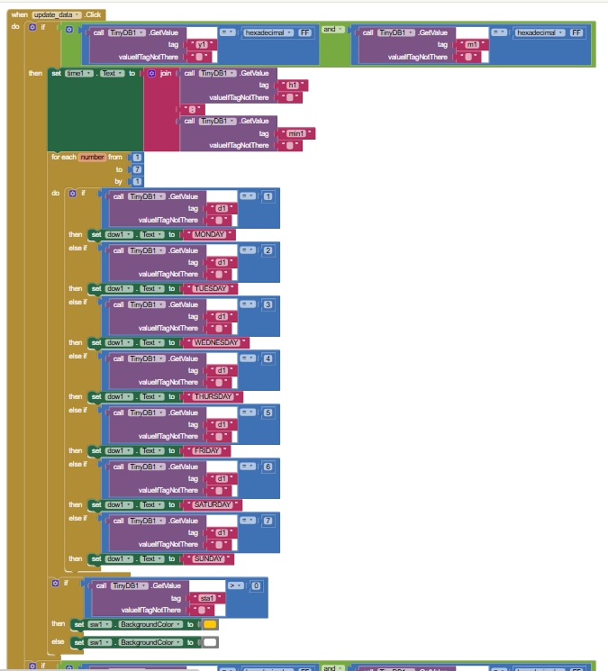
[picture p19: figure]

Figure 32. update_data blocks of Screen 4 For updating data, we will check for the month and year data if they’re equal to FF or not. If yes, we will update the interface of the app in the format of time and day in week (Monday, Tuesday, Wednesday, etc). The day data will be used to display the day in week data under the form of number from 1 to 7 (Monday to Sunday). With each day, d will get it’s suitable value.

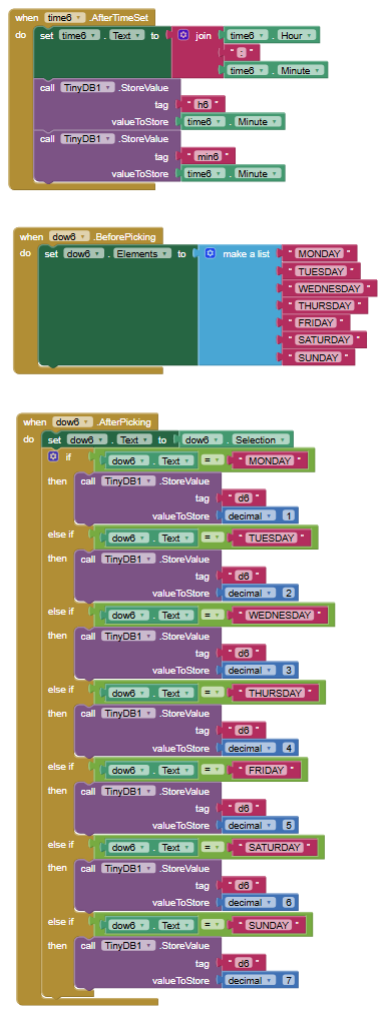
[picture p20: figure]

Figure 33. Alarms setting blocks of Screen 4 For setting time, it will be the same as previous one.
For setting day in the week, we will choose form a list of day include Monday to Sunday. After picking, the assigned number for each day will be stored into the d tag.

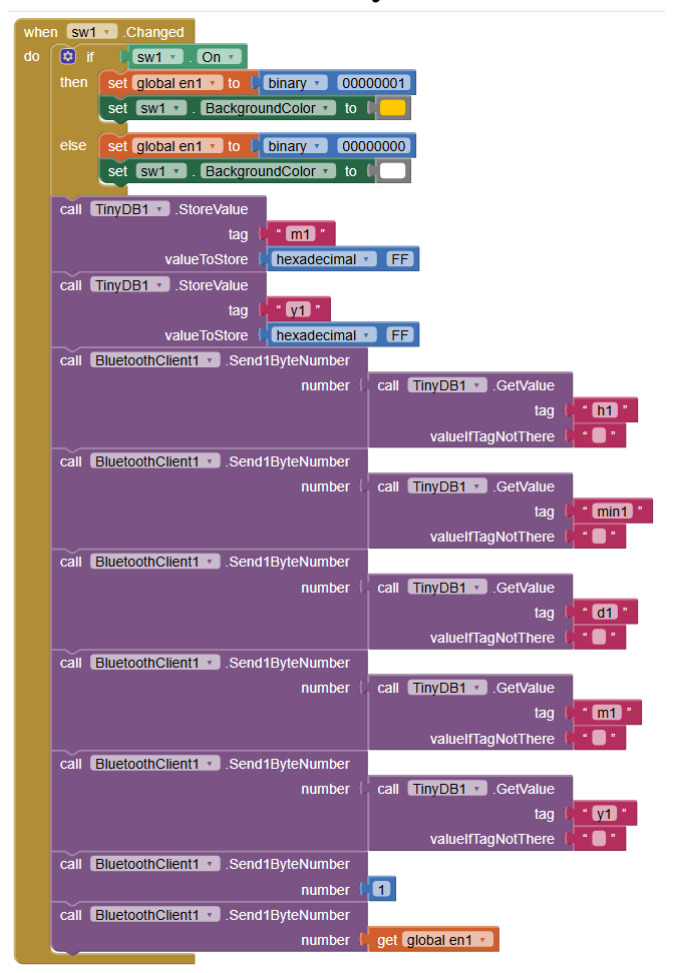
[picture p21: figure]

Figure 34. Sending data blocks of Screen 4 Sending data to STM32 is also the same when we want to adjust alarms in months.

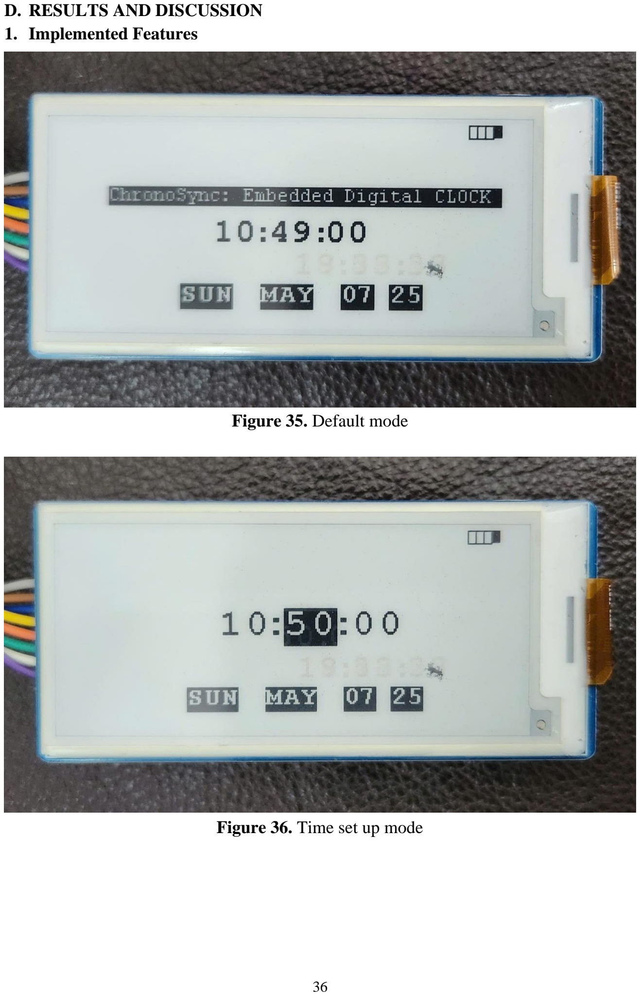
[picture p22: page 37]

D. RESULTS AND DISCUSSION

### 1. Implemented Features

Figure 35. Default mode

Figure 36. Time set up mode

Figure 37. Alarm data setup mode

Figure 38. Alarm view mode

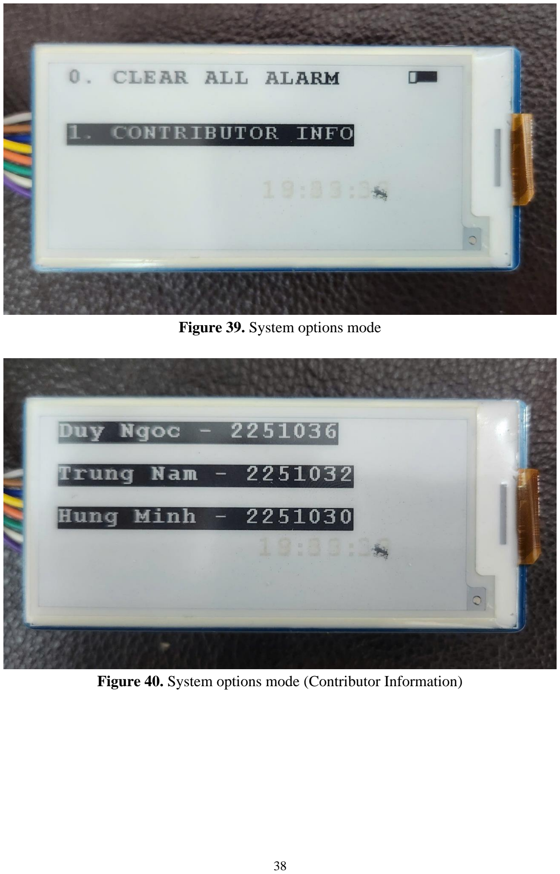
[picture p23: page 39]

Figure 39. System options mode

Figure 40. System options mode (Contributor Information)

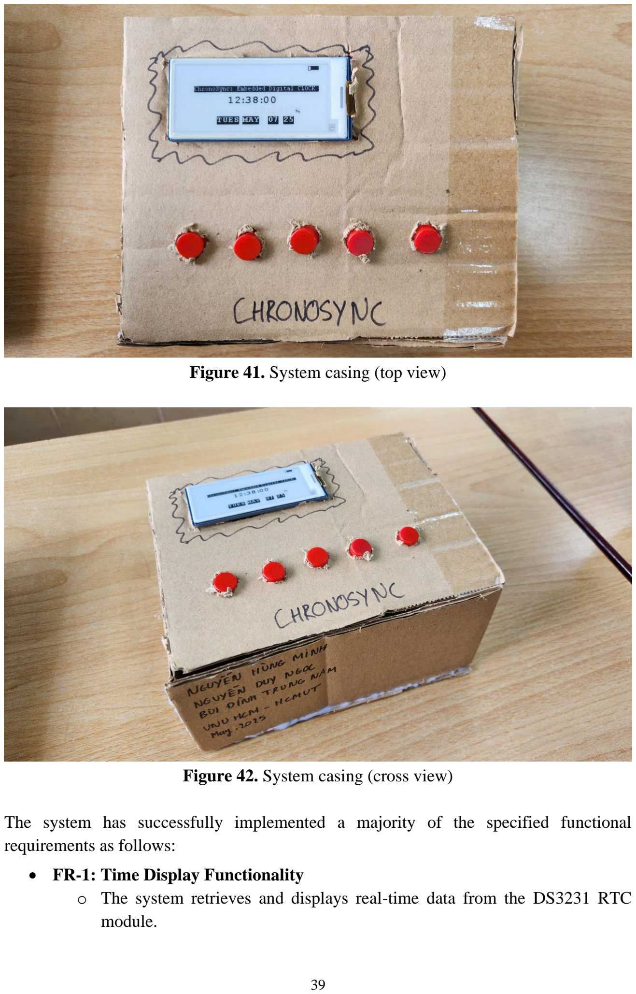
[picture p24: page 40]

Figure 41. System casing (top view)

Figure 42. System casing (cross view)

The system has successfully implemented a majority of the specified functional requirements as follows:

- FR-1: Time Display Functionality
- The system retrieves and displays real-time data from the DS3231 RTC module.

- Time is updated every second using an external interrupt generated by a 1 Hz square wave from the RTC.
- The display format includes hour, minute, day of the week, date, month, and year.
- FR-2: Alarm Management
- Users can configure up to 10 alarm entries. Each alarm includes fields for hour, minute, selection of day-of-week or date-of-month mode, the specific day or date value, and an ON/OFF flag.
- A hierarchical matching algorithm checks alarms against the real-time clock every second, starting from the ON/OFF status, followed by day/date, hour, minute, and finally second.
- If a match is found, the system activates a buzzer with a pre-defined melody pattern and displays alarm status.
- FR-3: Time and Alarm Setting via Physical Buttons
- Five physical buttons enable users to navigate through setup interfaces and adjust time or alarm parameters.
- The buttons support incrementing/decrementing values and navigating between fields.
- FR-4: Alarm Review and Editing
- A dedicated alarm review mode allows users to browse through saved alarm slots.
- While reviewing, users can toggle the ON/OFF status of an alarm or enter editing mode to adjust its configuration.
- FR-5: Time and Alarm Configuration via Mobile Application
- The system communicates with a mobile app through Bluetooth using an HC-05 module.
- Users can wirelessly send updated time and alarm configuration data, which is then decoded and applied to the system's internal state.
- FR-6: System Utility Features
- A system options mode is available in the user interface, allowing users to perform selected utility functions.
- Currently, the feature to clear all alarms is implemented and functional.
- FR-7: Physical Device Requirements
- The system is built on a compact PCB with all components placed for minimal size and optimal routing.
- Although the final enclosure is handmade from carton for prototyping, the layout complies with dimensions suitable for future ABS/Mica casing.
- FR-8: Power Efficiency and Display Technology
- The device uses a 2.9-inch E-Ink display to ensure ultra-low power consumption during idle states, as it only consumes energy during screen refresh.

- The power system is designed around a TPS54231 buck converter and AMS1117 linear regulator to support efficient voltage regulation.

### 2. Testing and Debugging Process

During system integration, several functional conflicts and implementation challenges were encountered and resolved collaboratively:

- Button Debounce and Press Type Detection: Short and long button presses were distinguished using debounced input readings and timing thresholds. Without debouncing, erratic behavior was observed during mode transitions.
- System Mode Handling vs. E-Ink Display Timing: The E-Ink display requires a physical delay to refresh. Mode-switching logic and button handlers were designed to avoid interrupting display operations by introducing non-blocking synchronization.
- RTC and EEPROM I²C Communication: Conflicts arose when simultaneous I²C operations were attempted. The I²C routines were made atomic and managed using state flags to prevent bus contention.
- RTC Square Wave Output to STM32 Interrupt: The DS3231 was configured to generate a 1 Hz square wave signal. This was connected to an external interrupt on the STM32 to ensure precise timekeeping without relying on software timers.
- Time and Alarm Data Encoding/ Decoding: Time and alarm structures were encoded compactly for storage in EEPROM. Bit-level packing was used to reduce memory footprint while preserving data integrity.
- Efficient Alarm Matching Algorithm: Alarm match logic was optimized to reduce computation time by applying early exits: if the alarm is disabled, or if the day/date does not match, the handler skips remaining checks to save power and processing time.
- Alarm Ring Melody Management: When an alarm triggers, a melody is played using the buzzer. Timed sequences were designed to avoid interference with main logic and user interactions.
- System State Management Across Modes: Transitions between system modes were carefully managed to preserve relevant state variables and reset temporary fields only when necessary (e.g., upon exit).
- Context-Aware Button Handling: Button behavior was made context-sensitive based on the current and previous modes. This ensures intuitive navigation and prevents incorrect action triggering across modes.

### 3. Challenges and Solutions

While the project has successfully achieved the majority of its functional requirements, several features and performance constraints remain partially completed or untested due to time limitations, hardware constraints, and integration challenges. The tables below outlines these issues, the underlying causes, and proposed solutions for future improvement.

### 3.1. Functional Limitations

Challenge | Description | Proposed Solution
Button long press: continuous increment/decrement | Although long press detection is implemented, continuous value increment/decrement during time and alarm setup has not been realized. This limitation is due to the blocking nature of E-Ink display refresh cycles, which interrupt the periodic update required for repeated input changes. | Refactor the button handler to operate asynchronously from the display update process. Use a timer-based interrupt or non-blocking polling mechanism to trigger value changes independently of the display state. Delay or queue display refreshes to avoid conflicting with active input.
Debounce delay conflicts with E-Ink display refresh | The debounce logic includes a short delay that conflicts with the slow physical refresh time of the E-Ink display, causing visual artifacts or latency during frequent user input. | Separate the display update logic into a non-blocking task or conditional refresh trigger to minimize impact on button handling routines.
Mobile app functionality incomplete | The mobile app does not yet support real-time clock synchronization display, alarm list editing, or battery percentage reporting. | Extend the BLE communication protocol to support two-way synchronization for time and alarm slots. Add new UUIDs for battery status and system flags. Use periodic polling or notification callbacks from the embedded system.
Display interface not fully designed | The E-Ink display currently shows raw system values without a user-friendly graphical layout or labels. | Design a cleaner UI using bitmap icons, improved font layout, and logical screen partitioning. Consider integrating a lightweight UI library compatible with E-Ink displays.
System option functions unimplemented | The functions for factory reset and display test patterns in System Options Mode are defined in UI but not yet programmed. | Add handler functions for each feature. Factory reset can clear EEPROM and reset system state. Display test can toggle through predefined patterns or contrast checks.
No finalized enclosure (Mica/ABS) | The prototype is housed in a temporary carton-based casing, lacking robustness or long-term usability. | Design a 3D-printable case using Mica or ABS plastic. Ensure proper cutouts for display, buttons, and ventilation. Future versions can consider injection molding for product-scale development.
Battery holder not integrated into PCB | Although footprint and schematic are prepared for battery power, no actual battery is installed. Power is currently supplied through DC adapter only. | Solder the lithium-ion battery holder, verify the power path, and enable real-time voltage measurement through ADC. Re-enable battery percentage display

logic using pre-defined conversion formula from ADC input.

### 3.2. Constraints and Testing Limitations

Constraint | Description | Proposed Solution
C-1.2: Alarm matching time < 50 ms | The alarm matching logic is designed for optimized performance, but its actual execution time has not been benchmarked. | Use HAL_GetTick() or STM32 cycle counters to measure time taken per loop. Optimize further by breaking out early from comparison steps if mismatches are found.
C-2.3: EEPROM access time < 10 ms | Read/write operations to EEPROM are fast in practice, but precise measurement is yet to be conducted. | Benchmark write and read durations using debug pins or live expression timing, and optimize by minimizing repeated EEPROM access during frequent tasks.
C-4.3: Power consumption < 3 mW | The system is designed for low power with an E-Ink display and efficient DC/DC converters, but actual power draw has not been measured. | Use a precision power analyzer to measure current draw in typical idle and active states. Confirm average consumption over time and identify optimization opportunities in idle states (e.g., reduce ADC/UART activity).

### 4. Performance Evaluation

The system has been evaluated against the majority of its defined performance constraints. The following summarizes the constraints that have been successfully verified, along with their key performance indicators:

C-1: Timing and Accuracy

- C-1.1 – Time Deviation < ±3 ppm at Room Temperature: The system integrates the DS3231 RTC, which provides ±2 ppm accuracy via its built-in temperature-compensated crystal oscillator. Testing over 24 hours revealed no observable drift, confirming compliance.
- C-1.3 – Maintain Accurate Time for ≥30 Days on Power Loss: The DS3231 retains real-time data via a coin-cell backup, with a standby time exceeding several years under standard conditions. This satisfies the 30-day minimum requirement.

C-2: Alarm Storage

- C-2.1 – Data Persistence After Power Loss: Alarm configurations stored in the AT24C64D EEPROM were successfully retained and retrieved after multiple power cycles without data corruption.
- C-2.2 – Total Alarm Storage < 50 Bytes: Each alarm slot requires 4 bytes; 10 alarms occupy a total of 40 bytes, meeting the storage limit with headroom for future expansion.

C-3: Input Responsiveness

- C-3.1 – Short Press Detected in <30 ms: Input detection is optimized with hardware and software debouncing, achieving press detection within ~20–30 ms.
- C-3.2 – Long Press Detected After 600 ms: The long press threshold is configured and validated at 600 ms, confirming proper event handling.
- C-3.3 – False Trigger Rate <1 per 100 Presses: System testing confirmed reliable debouncing with no noticeable false triggers across multiple test cycles.

C-4: Power and Energy Constraints
- C-4.1 – Battery Operated (4× 2000 mAh, 3V): Although the battery holder has not been soldered onto the PCB, the design supports full operation on 3V Li-ion batteries and includes ADC-based voltage monitoring.

C-5: Physical Dimensions

- C-5.1 – Device Dimensions ≤ 15×15×8 cm: The fabricated prototype meets dimensional constraints, with the final assembly comfortably within specified limits.
- C-5.2 – Weight < 300 g:The total system, excluding battery, weighs approximately 150 g. Full integration is projected to remain under the 300 g limit.

In summary, the system fulfills its core performance metrics related to accuracy, memory reliability, input responsiveness, and modular software design. Remaining constraints that have not been verified are discussed in the next section.

E. CONCLUSION

The ChronoSync embedded digital clock system has been successfully developed to meet the core functional requirements of timekeeping, alarm scheduling, user configuration via physical buttons and Bluetooth application, and low-power operation using an E-Ink display. Through a structured development process, the team integrated hardware and firmware components efficiently, ensuring modularity, maintainability, and expandability.

Despite the project’s achievements, several features remain partially implemented or unverified, including enhanced mobile app capabilities, certain system utility functions, battery integration, and performance validation against specific timing and power constraints. These limitations primarily arose due to hardware prototyping constraints and time limitations in the academic schedule.

Nonetheless, the ChronoSync system has demonstrated solid design principles, reliable functionality, and responsive interaction under real-world operating conditions. Future improvements will focus on completing the remaining features, optimizing power efficiency, and enhancing user interface design, both in hardware form factor and graphical layout.

This project provided valuable hands-on experience in embedded systems design, peripheral interfacing, real-time programming, and system-level debugging – bridging theoretical concepts with practical implementation in a collaborative engineering context.

F. REFERENCES
1. STMicroelectronics, CD00161566 - STM32F103C8T6 Datasheet – ARM Cortex-M3 32-bit MCU, Rev. 18, Jul. 2023. [Online]. Available: https://www.st.com/resource/en/datasheet/cd00161566.pdf
2. Microchip Technology Inc., AT24C64D - 64-Kbit Serial EEPROM I2C Compatible (Two-Wire Interface), DS20005937A, Feb. 2016. [Online]. Available: https://ww1.microchip.com/downloads/aemDocuments/documents/MPD/ProductDocuments/DataSheets/AT24C64D-64-Kbit-Serial-EEPROM-I2C-Compatible-Two-Wire-DS20005937.pdf (https://ww1.microchip.com/downloads/aemDocuments/documents/MPD/ProductDocuments/DataSheets/AT24C64D-64-Kbit-Serial-EEPROM-I2C-Compatible-Two-Wire-DS20005937.pdf)
3. Analog Devices, DS3231 - Extremely Accurate I²C-Integrated RTC with TCXO and Crystal, Rev. 11, Jul. 2020. [Online]. Available: https://www.analog.com/media/en/technical-documentation/data-sheets/ds3231.pdf
4. Shenzhen Ehong Technology Co., Ltd., HC-05 Bluetooth Module Datasheet. [Online]. Available:
https://components101.com/sites/default/files/component_datasheet/HC-05%20Datasheet.pdf (https://components101.com/sites/default/files/component_datasheet/HC-05%20Datasheet.pdf)
5. Waveshare Electronics, 2.9inch E-Ink Display Module Datasheet, [Online]. Available: https://www.waveshare.com/w/upload/e/e6/2.9inch_e-Paper_Datasheet.pdf

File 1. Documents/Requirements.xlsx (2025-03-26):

1 | The clock must be compact and portable.
1.1 | The dimensions of the clock shall be 8 cm x 15 cm x 4 cm.
1.2 | The clock case shall be made of Mica or ABS plastic (3D printed).
1.3 | The total weight of the device shall not exceed 300 g.
2 | The clock must have an intuitive and accessible user interface. | in progress
2.1 | The clock shall include buttons and numeric buttons for operation.
2.1.1 | The buttons shall be made of rubber for better tactile feedback.
2.1.2 | The button response time shall be < 50 ms.
2.2 | The clock shall have an LCD screen for displaying time and other information.
2.2.1 | The LCD screen resolution shall be 296 × 128 px.
2.2.2 | The LCD screen shall operate at 60 Hz refresh rate (reduced to 1-2 Hz in power-saving mode).
2.2.3 | The LCD screen brightness shall range between 200 - 500 nits.
3 | The clock must have long battery life and low power consumption. | not yet
3.1 | The clock shall use a lithium-ion battery.
3.1.1 | The charging power shall be 5 W (5 V - 1 A).
3.1.2 | The battery capacity shall be 2000 mAh.
3.2 | The total power consumption shall be < 1 W.
3.3 | A power-saving mode shall be available.
3.3.1 | The LCD screen shall turn off after 10 seconds of inactivity.
3.3.2 | The screen brightness shall be reduced by approximately 30-50% when needed.
3.3.3 | The screen refresh rate shall be reduced to 1-2 Hz in power-saving mode.
 | Battery monitor: ADC in (TNam) | addition
4 | The clock must display accurate time information. | done
4.1 | The clock shall display hours, minutes, and seconds.
4.1.1 | The time deviation shall be < 5 seconds per month.
4.1.2 | The clock shall use an RTC (Real-Time Clock) module to maintain accurate time.
4.2 | The clock shall display the day of the week, date, month, and year.
5 | The clock must support an alarm function. | done
5.1 | The clock shall allow storing up to 10 alarms.
5.1.1 | The alarms shall be retained even when the battery is depleted.
5.2 | The clock shall include an integrated speaker. | not yet
5.2.1 | The speaker shall be 1 - 3W.
5.2.2 | The speaker volume shall be > 70 dB.
 | Bluetooth - App | done

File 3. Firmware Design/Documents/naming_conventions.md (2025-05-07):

# **Naming Conventions for Embedded System Project**

This document outlines the naming conventions to be followed throughout the project to ensure consistency, readability, and maintainability of the code.

---

## **1. General Guidelines**
- Use **descriptive names** that clearly indicate the purpose of the variable, function, or constant.
- Use **lowercase with underscores (`_`)** for global variables.
- Use **camelCase** for local variables.
- Use **Upper_Camel_Snake_Case** (uppercase with the first letter of each word separated by underscores) for function names.
- Use **ALL_CAPS_WITH_UNDERSCORES** for macros and constants.
- Use **ALL_CAPS** for struct names.
- Avoid abbreviations unless they are widely understood (e.g., `ADC`, `UART`, `RTC`).

---

## **2. Variables**
### **2.1 Global Variables**
- Use **lowercase with underscores (`_`)** for global variables.
  - Example: `rtc_trigger_flag`, `adc_data`, `uart_rx_flag`.
- Prefix global variables with the module or purpose if necessary to avoid naming conflicts.
- Use `volatile` for variables shared between interrupts and the main program.

### **2.2 Local Variables**
- Use **camelCase** for local variables.
  - Example: `setTime`, `getTime`, `ctrlTime`.

### **2.3 Flags**
- Use the suffix `_flag` for boolean variables that act as flags.
  - Example: `rtc_trigger_flag`, `adc_valid_flag`, `uart_rx_flag`.

### **2.4 Structs**
- Use **ALL_CAPS** for struct names.
  - Example: `TIME`, `ALARM`.
- Use **lowercase with underscores (`_`)** for struct members.
  - Example: `second`, `minute`, `hour`.

---

## **3. Functions**
- Use **Upper_Camel_Snake_Case** for function names.
- Use a verb or action word as the prefix to indicate the function's purpose.
  - Example: `Time_Init`, `Time_Set`, `Alarm_Check`.
- For module-specific functions, prefix the function name with the module name.
  - Example: `Time_Get`, `Alarm_Set`.

---

## **4. Constants and Macros**
- Use **ALL_CAPS_WITH_UNDERSCORES** for constants and macros.
- Prefix constants with the module or purpose.
  - Example: `DS3231_ADDRESS`, `EEPROM_ADDR`.
- Use meaningful names that describe the constant's purpose.

---

## **5. File-Specific Conventions**
- Use `USER CODE BEGIN` and `USER CODE END` comments to mark user-defined sections.
- Group related variables and functions together for better readability.

---

## **6. Additional Notes**
- Follow the conventions consistently across all files in the project.
- Use comments to explain the purpose of variables, functions, and constants where necessary.
- Avoid using magic numbers; define them as constants with meaningful names.

By adhering to these conventions, the codebase will remain clean, consistent, and easy to understand for all contributors.

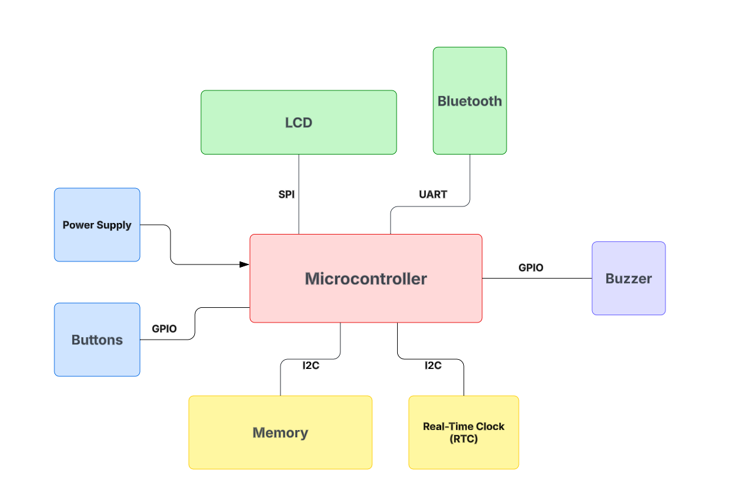
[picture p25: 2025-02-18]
1. Documents/Block-diagram.png

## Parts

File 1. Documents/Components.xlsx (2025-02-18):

Number | Components | Link | Explanation
1 | LED SMD (Surface-Mount LED) | https://www.thegioiic.com/led-xanh-duong-0805-dan-smd-trong-suot | Used as an indicator for power, notifications, or alarms. The SMD package allows for compact placement on the PCB while maintaining high brightness.
2 | SS54 SMA (Schottky Diode, 5A, 40V) | https://www.thegioiic.com/ss54-sma-diode-shotky-5a-40v | A Schottky diode is chosen for its low forward voltage drop, reducing power loss in the power regulation circuit. It also ensures fast switching, making it ideal for the DC power input stage and buck converter protection.
3 | DC5521 Jack (DC Power Connector, 2.1mm) | https://www.thegioiic.com/dc5521-dau-noi-nguon-dc-cai-5521-han-pcb-kim-2-1mm | This standard DC jack allows the clock to be powered from an external power adapter. It ensures easy connection and replacement of power sources, supporting battery charging or direct operation.
4 | SMD Inductor 10uH, 1.8A | https://www.thegioiic.com/-thanh-ly-cuon-cam-dan-smd-cdrh127-1280-680-68uh-3-2a | Inductors are essential in switching power supplies like buck converters. This 10µH inductor helps smooth out current in the TPS54231 buck converter, ensuring stable voltage regulation while improving efficiency.
5 | TPS54231DR (2A Buck Converter, Step-Down Voltage Regulator) | https://www.thegioiic.com/tps54231dr-ic-dieu-chinh-giam-ap-2a-8-soic | This DC-DC buck converter efficiently converts higher input voltage (e.g., 12V) to a lower voltage (e.g., 5V or 3.3V), optimizing power usage for the microcontroller and peripherals.
6 | AMS1117-3.3V (Voltage Regulator, 3.3V, 1A) | https://www.thegioiic.com/ams1117-3-3v-ic-on-ap-3-3v-1a-sot-223 | Many components (STM32, RTC, EEPROM, Bluetooth) require a stable 3.3V power supply. The AMS1117 provides a reliable 3.3V output with sufficient current capability.
7 | SMD Capacitor 22uF | https://www.thegioiic.com/tu-nhom-smd-100uf-35v-8x10-5mm | Used for power line decoupling to smooth voltage fluctuations, ensuring stable operation for power-sensitive components.
8 | SMD Capacitor 0805, 100nF (0.1µF) | https://www.thegioiic.com/tu-gom-0805-100nf-0-1uf-50v | Acts as a bypass capacitor to reduce high-frequency noise and provide local energy storage near ICs, improving reliability.
9 | SMD Resistor 10kΩ, 0805 | https://www.thegioiic.com/dien-tro-10-kohm-0805-1- | Used in pull-up/pull-down circuits for buttons and signal lines. Also serves as a current-limiting resistor where needed.
10 | STM32F103C8T6 (32-bit ARM Cortex-M3 Microcontroller, 72MHz, 64KB Flash) | https://www.thegioiic.com/stm32f103c8t6-32-bit-arm-cortex-m3-microcontroller-72mhz-64kb-flash-48-lqfp | Acts as the brain of the system, handling display control, Bluetooth communication, timekeeping, alarm management, and user inputs. The low-power ARM Cortex-M3 core ensures efficient operation.
11 | 8MHz Crystal Oscillator | https://www.thegioiic.com/thach-anh-8mhz-2-chan-smd-hc49-s | Provides a stable clock signal for the STM32, ensuring precise operation and synchronization with peripherals.
12 | 32.768kHz Crystal Oscillator | https://www.thegioiic.com/thach-anh-fc-135-32-768khz-3215 | Used with the DS3231 RTC module to maintain an accurate time reference with very low power consumption.
13 | Tactile Push Button (12x12mm) | https://hshop.vn/mach-1-nut-nhan-tact-switch-12x12mm | Allows the user to set alarms, adjust time, and control other functions. The large size ensures easy usability.
14 | E-Ink LCD Display (2.9-inch, Waveshare) | https://hshop.vn/man-hinh-waveshare-2-9-inch-e-ink-display-module-three-color-b | E-Ink technology consumes power only when updating, making it ideal for battery-powered clocks. It also provides excellent readability in bright environments.
15 | HC-05 Bluetooth Module | https://hshop.vn/mach-thu-phat-bluetooth-hc-05-do-ra-chon-master | Enables wireless communication with smartphones for time synchronization, alarm configuration, and remote settings.
16 | DS3231SN (Real-Time Clock - RTC, Temperature Compensated) | https://www.thegioiic.com/ds3231sn-ic-rtc-clock-calendar-16-sop | Provides real-time clock functionality with an accuracy of ±2ppm, ensuring minimal drift and eliminating the need for frequent manual adjustments.
17 | AT24C64D EEPROM (64Kbit, 8-SOIC) | https://www.thegioiic.com/at24c64d-sshm-t-ic-eeprom-64kbit-8-soic | Ensures that alarm settings, user preferences, and other data remain stored even when power is lost.

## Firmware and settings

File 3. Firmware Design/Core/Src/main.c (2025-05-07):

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
/* Includes ------------------------------------------------------------------*/
#include "main.h"
#include "adc.h"
#include "i2c.h"
#include "spi.h"
#include "usart.h"
#include "gpio.h"

/* USER CODE BEGIN Includes */

#include "stdbool.h"
#include "stdio.h"
#include "string.h"
#include "EPD_Test.h"
/* USER CODE END Includes */

/* USER CODE BEGIN PTD */

// Enum for alarm day of week or date of month mode
// typedef enum
// {
//   DAY_OF_WEEK_MODE,
//   DATE_OF_MONTH_MODE,
//   NOT_USED_MODE
// } ALARM_DY_DT_MODE;

// Enum for button debounce states
typedef enum 
{
  BUTTON_RELEASED,    // Button is not pressed (HIGH state)
  BUTTON_WAITING,     // Button is pressed (LOW state) and waiting for debounce delay
  BUTTON_PRESSED,     // Button is pressed (LOW state)
} BUTTON_STATE;

// Enum for system modes
//typedef enum {
// DEFAULT_MODE,
// TIME_SETUP_MODE,
// ALARM_SETUP_MODE,
// ALARM_VIEW_MODE,
// ALARM_ACTIVE_MODE,
// SYSTEM_OPTIONS_MODE
//} SYSTEM_MODE;

// Enum for system parameters to be selected for modification
// typedef enum
// {
//   TIME_MINUTE,   // Set minutes value
//   TIME_HOUR,     // Set hours value
//   TIME_DOW,      // Set day of the week value
//   TIME_DOM,      // Set date of the month value
//   TIME_MONTH,    // Set month value
//   TIME_YEAR,     // Set year value
// } TIME_SETUP_CURSOR;

// Enum for parameter selection in Alarm Setup Mode
// typedef enum
// {
//   ALARM_MINUTE,   // Set minutes value
//   ALARM_HOUR,     // Set hours value
//   ALARM_DY_DT,    // Set day of week or date of month (1 = day of week, 0 = date of month, 2 = not used)
//   ALARM_DOW_DOM,  // Set day of the week or date of the month value
//   ALARM_ON_OFF,   // Set ON/OFF state
// } ALARM_SETUP_CURSOR;

// Structure of 7 one-byte unsigned characters to store time values
//typedef struct
//{
//	uint8_t second;       // Seconds: 0-59
//	uint8_t minute;       // Minutes: 0-59
//	uint8_t hour;         // Hours: 0-23
//	uint8_t dayofweek;    // Day of the week: 1-7 (1 = Sunday, 2 = Monday, ..., 7 = Saturday)
//	uint8_t dateofmonth;  // Date of the month: 1-31
//	uint8_t month;        // Month: 1-12
//	uint8_t year;         // Year: 0-99 (0 = 2000, 1 = 2001, ..., 99 = 2099)
//} TIME_DATA;

// // Structure of 4 one-byte unsigned characters to store alarm values
typedef struct
{
  uint8_t           second;   // Seconds: 0-59 (MSB = 1 for ON, 0 for OFF)
  uint8_t           minute;   // Minutes: 0-59
  uint8_t           hour;     // Hours: 0-23
  ALARM_DY_DT_MODE  dy_dt;    // Select: DAY_OF_WEEK_MODE, DATE_OF_MONTH_MODE, NOT_USED_MODE
  uint8_t           dow_dom;  // Day of the week: 1-7 (1 = Sunday, 2 = Monday, ..., 7 = Saturday), or Date of the month: 1-31
  bool              on_off;   // true = ON, false = OFF
} ALARM_DATA;
// typedef enum
// {
//   CLEAR_ALL_ALARM,
//   CONTRIBUTOR_INFO,
// } SYSTEM_OPT_CURSOR;
// Struct representing each button with debouncing state
typedef struct 
{
  GPIO_TypeDef    *gpio_port; // GPIO port of the button      
  uint16_t        gpio_pin;   // GPIO pin of the button
  uint8_t         index;      // Index of the button (0-4)
  BUTTON_STATE    state;      // Current state of the button
  uint32_t        start_tick; // Start time of the debounce timer
  volatile bool   int_flag;   // Set when button interrupt is triggered
  volatile bool   press_flag; // Set when button is pressed
  volatile bool   hold_flag;  // Set when button is held down
  volatile bool   latch;  // Set when button is pressed or held (once only)
} BUTTON_DATA;

// Struct for system state
// typedef struct
// {
//   SYSTEM_MODE         mode;               // Current system mode
//   SYSTEM_MODE         past_mode;          // Previous system mode
//   TIME_SETUP_CURSOR   time_setup_cursor;  // Cursor of selection for Time Setup Mode
//   ALARM_SETUP_CURSOR  alarm_setup_cursor; // Cursor of selection for Alarm Setup Mode
//   uint8_t             alarm_view_cursor;  // Cursor of selection for Alarm View Mode
//   SYSTEM_OPT_CURSOR   system_opt_cursor;  // Cursor of selection for System Options Mode
//   uint8_t             battery_display;    // Battery percentage to be displayed: 100, 75, 50, 25, 0
// } SYSTEM_STATE;

// Struct for time parameters to be modified
// typedef struct
// {
//   uint8_t           minute;   // Minutes: 0-59
//   uint8_t           hour;     // Hours: 0-23
//   uint8_t           dow;      // Day of the week: 1-7 (1 = Sunday, 2 = Monday, ..., 7 = Saturday), or Date of the month: 1-31
//   uint8_t           dom;      // Date of the month: 1-31, or Day of the week: 1-7, or not used: 0
//   uint8_t           month;    // Month: 1-12
//   uint8_t           year;     // Year: 0-99 (0 = 2000, 1 = 2001, ..., 99 = 2099)
// } TIME_SETUP_DATA;
// Struct for alarm parameters to be modified
// typedef struct
// {
//   uint8_t           minute;   // Minutes: 0-59
//   uint8_t           hour;     // Hours: 0-23
//   ALARM_DY_DT_MODE  dy_dt;    // Select: DAY_OF_WEEK_MODE, DATE_OF_MONTH_MODE, NOT_USED_MODE
//   uint8_t           dow_dom;  // Day of the week: 1-7 (1 = Sunday, 2 = Monday, ..., 7 = Saturday), or Date of the month: 1-31
//   bool              on_off;   // true = ON, false = OFF
// } ALARM_SETUP_DATA;;

FLAG_SYSTEM flag_sSystem_mode = {1, 1, 1, 1, 1};
/* USER CODE END PTD */

/* USER CODE BEGIN PD */

// Slave address of DS3231 RTC module
#define DS3231_ADDR 0xD0

// I2C handle for DS3231 RTC module
#define DS3231_I2C &hi2c1

// Slave address of AT24C64D EEPROM module
#define EEPROM_ADDR 0xA0

// I2C handle for AT24C64D EEPROM module
#define EEPROM_I2C &hi2c1

// Number of alarms in the EEPROM module
#define ALARM_SLOT_NUM 10 

// Address of alarm slot pointer in EEPROM module (right next to the final alarm slot)
#define ALARM_SLOT_PTR_ADDR (ALARM_SLOT_NUM * 4)

// Active state of buttons
#define BUTTON_ACTIVE GPIO_PIN_RESET

// Debounce threshold in milliseconds
#define BUTTON_DEBOUNCE_DELAY 30

// Button hold threshold in milliseconds
#define BUTTON_HOLD_TH 600

// Button hold cycle in milliseconds
#define BUTTON_HOLD_CYCLE 250

// Number of system modes
#define SYSTEM_MODE_NUM 6

// 
#define ALARM_VIEW_CURSOR_MAX 9
#define SYSTEM_OPT_CURSOR_MAX 1

#define SYSTEM_CURSOR_MAX 9

#define DISPLAY_DELAY 1
// Active state of the buzzer
#define BUZZER_ACTIVE GPIO_PIN_SET
#define BUZZER_INACTIVE GPIO_PIN_RESET

// Buzzer cycle number for alarm sound
#define BUZZER_CYCLE_NUM 10

// Buzzer delay in milliseconds
#define BUZZER_SHORT_DELAY 100
#define BUZZER_MEDIUM_DELAY 300
#define BUZZER_LONG_DELAY 500
/* USER CODE END PD */


/* USER CODE BEGIN PV */

/* SYSTEM ==========================================*/
// Global variable to store the current system mode and selected parameter
SYSTEM_STATE system_state = {0};

// Global variable to store the system parameters to be modified
TIME_SETUP_DATA time_setup_data = {0};
ALARM_SETUP_DATA alarm_setup_data = {0};

/* RTC & EEPROM ====================================*/
// Variable to store the time values received from the RTC module every second
TIME_DATA time_get_data = {0};

// Array to store the alarm values received from the EEPROM module
volatile ALARM_DATA alarm_get_data [ALARM_SLOT_NUM] = {0}; 

// Pointer to the next free alarm in the EEPROM module
uint8_t alarm_slot_ptr;

// Flag for RTC trigger external interrupt (RTC Interrupt Flag) on PB4 (Activated every second)
volatile bool rtc_int_flag = false;

// Debugging: Track the number of alarm activations
uint8_t debug_alarm_activate_ctr = 0;
bool alarm_active_flag = false; 
volatile bool debug_rtc_int = false;

/* BUTTON ========================================*/
// Debugging: Track if the button is pressed or not
volatile uint8_t debug_button_counter[5] = {0};

// Global instances of DEBOUNCE_BUTTON for each button
BUTTON_DATA button0 = {GPIOB, BUTTON0_IN12_Pin, 0, BUTTON_RELEASED, 0, false, false, false, false};
BUTTON_DATA button1 = {GPIOB, BUTTON1_IN13_Pin, 1, BUTTON_RELEASED, 0, false, false, false, false};
BUTTON_DATA button2 = {GPIOB, BUTTON2_IN14_Pin, 2, BUTTON_RELEASED, 0, false, false, false, false};
BUTTON_DATA button3 = {GPIOB, BUTTON3_IN15_Pin, 3, BUTTON_RELEASED, 0, false, false, false, false};
BUTTON_DATA button4 = {GPIOA, BUTTON4_IN8_Pin,  4, BUTTON_RELEASED, 0, false, false, false, false};

/* ADC ==========================================*/
// Flag for ADC interrupt (ADC Valid Flag)
volatile bool adc_valid_flag = false;   

// Variable for ADC raw data
uint16_t adc_data;           

// Variable for battery percentage (raw data * 100 / 4095 (2^12))
uint16_t battery_percentage; 

/* UART ========================================*/
// Flag for UART interrupt (UART Receive Flag)
volatile bool uart_rx_flag = false;
volatile bool uart_tx_flag = false;
// Variable for UART receive data
uint8_t uart_rx_data[7];

// Variable for UART transmit data
uint8_t uart_tx_data[7];

// Variables to store decoded values received from the UART module
uint8_t uart_hour;      //uart_rx_data[0]; this can also be used to set the mode of the UART module
uint8_t uart_minute;    //uart_rx_data[1]
uint8_t uart_dow;       //uart_rx_data[5]
uint8_t uart_day;       //uart_rx_data[2]; this can also be used to define the day of the week in mode 3
uint8_t uart_month;     //uart_rx_data[3]
uint8_t uart_year;      //uart_rx_data[4]
uint8_t uart_alarmNum;	//uart_rx_data[5] number of the alarm (alarm number1/ alarm number2/...)
uint8_t uart_alarmSta;	//uart_rx_data[6] status of the alarm (on/off)

// Variable to store mask values for the modes of the UART module
//    0. Quit Mode:     0b11000000 
//    1. Time Setup:    0b11110000 (ON)/ 0b11000000 (OFF)
//    2. Alarm Setup    0b01110000 (ON)/ 0b11000000 (OFF)
//    3. Update Alarms: 0b11111111
uint8_t uart_mode;		  
                        
// Variable to indicate the mode of the UART module (1, 2, or 3)
uint8_t uart_appMode = 0;

// Variable to store the number of alarms sent to the App (0-10)
uint8_t sentCount = 0; 

//Variables for alarms:
uint8_t alarm_Info[10][7]; // 10 alarms, each alarm has 7 values (hour, minute, day, month, year, number, status)

/* BUZZER ======================================*/
// Buzzer cycle number
uint8_t buzzer_cycle = 0; 

// Buzzer phase number
uint8_t buzzer_phase = 0; 

// Start time of the buzzer cycle
uint32_t buzzer_tick = 0; 


// time save
TIME_DATA time_setup = {0};
// alarm data
ALARM_DATA_SETUP_MODE sParam_data_alarm_setup_mode_1  = {0};
ALARM_DATA_SETUP_MODE sParam_data_alarm_setup_mode_2  = {0};
ALARM_DATA_SETUP_MODE sParam_data_alarm_setup_mode_3  = {0};
ALARM_DATA_SETUP_MODE sParam_data_alarm_setup_mode_4  = {0};
ALARM_DATA_SETUP_MODE sParam_data_alarm_setup_mode_5  = {0};
ALARM_DATA_SETUP_MODE sParam_data_alarm_setup_mode_6  = {0};
ALARM_DATA_SETUP_MODE sParam_data_alarm_setup_mode_7  = {0};
ALARM_DATA_SETUP_MODE sParam_data_alarm_setup_mode_8  = {0};
ALARM_DATA_SETUP_MODE sParam_data_alarm_setup_mode_9  = {0};
ALARM_DATA_SETUP_MODE sParam_data_alarm_setup_mode_10 = {0};

SYSTEM_PARAM_DATA_ALARM_VIEW_MODE sParam_data_alarm_view_mode = {
  &sParam_data_alarm_setup_mode_1,
  &sParam_data_alarm_setup_mode_2,
  &sParam_data_alarm_setup_mode_3,
  &sParam_data_alarm_setup_mode_4,
  &sParam_data_alarm_setup_mode_5,
  &sParam_data_alarm_setup_mode_6,
  &sParam_data_alarm_setup_mode_7,
  &sParam_data_alarm_setup_mode_8,
  &sParam_data_alarm_setup_mode_9,
  &sParam_data_alarm_setup_mode_10
};
/* USER CODE END PV */

void SystemClock_Config(void);
/* USER CODE BEGIN PFP */

// Function to convert a normal decimal number to binary coded decimal (BCD)
uint8_t Dec_To_BCD(int val);

// Function to convert a binary coded decimal (BCD) value to a normal decimal number
int BCD_To_Dec(uint8_t val);

// Function to initialize RTC module
void Time_Init (uint8_t sec, uint8_t min, uint8_t hour, uint8_t dow, uint8_t dom, uint8_t month, uint8_t year);

// Function to initially set time to the RTC module through I2C interface (Run only once after reset the RTC)
void Time_Set (uint8_t sec, uint8_t min, uint8_t hour, uint8_t dow, uint8_t dom, uint8_t month, uint8_t year);

// Function to get time from the RTC module through I2C interface
void Time_Get (volatile TIME_DATA *time_get_data);

// Function to control settings of the RTC module (Alarm 1)
void Time_Ctrl (uint8_t mode, uint8_t sec, uint8_t min, uint8_t hour, uint8_t dow_dom, bool dy_dt);

// Function to write a single alarm to the EEPROM module
void Alarm_Set (uint8_t sec, uint8_t min, uint8_t hour, uint8_t dow_dom, ALARM_DY_DT_MODE dy_dt, bool on_off, uint8_t slot);

// Function to read a single alarm from the EEPROM module
void Alarm_Get (uint8_t slot, volatile ALARM_DATA *alarm_get_data);

// Function to clear a single alarm from the EEPROM module
void Alarm_Clear (uint8_t slot);

// // Function to check the alarms
void Alarm_Check (volatile TIME_DATA *time_get_data);
void Alarm_Ring (void);
// Functions to handle alarm slot pointer
void Alarm_Slot_Pointer_Set (void);
void Alarm_Slot_Pointer_Get (void);

// Debounce handler function to be called in main loop
void Button_Debounce(BUTTON_DATA *button);

// Button handler function to be called in main loop
void Button_Handle(void);

// System mode handlers
void System_Default_Mode_Handle (BUTTON_DATA *button);
void System_Time_Setup_Mode_Handle (BUTTON_DATA *button);
void System_Alarm_Setup_Mode_Handle (BUTTON_DATA *button);
void System_Alarm_View_Mode_Handle (BUTTON_DATA *button);
void System_Alarm_Active_Mode_Handle (BUTTON_DATA *button);
void System_Options_Mode_Handle (BUTTON_DATA *button);
// Update value to display E-ink code
void Update_alarm_data(void);

/* USER CODE END PFP */

/**
  * @brief  The application entry point.
  * @retval int
  */
int main(void)
{

  /* MCU Configuration--------------------------------------------------------*/

  /* Reset of all peripherals, Initializes the Flash interface and the Systick. */
  HAL_Init();

  /* Configure the system clock */
  SystemClock_Config();

  /* Initialize all configured peripherals */
  MX_GPIO_Init();
  MX_I2C1_Init();
  MX_ADC1_Init();
  MX_USART1_UART_Init();
  MX_SPI1_Init();
  /* USER CODE BEGIN 2 */

  bool uartDoneFlag = false;

    // Initially reset the buzzer
  HAL_GPIO_WritePin(BUZZER_GPIO_Port, BUZZER_Pin, BUZZER_INACTIVE); 
//  // Set time to the RTC module through I2C interface (Run only once after reset the RTC).
//  //    void Time_Set(uint8_t sec, uint8_t min, uint8_t hour, uint8_t dow, uint8_t dom, uint8_t month, uint8_t year)
//  Time_Set
//  (
//     0, // Seconds: 0-59
//    26, // Minutes: 0-59
//    11, // Hours: 0-23
//     4, // Day of the week: 1-7 (1 = Sunday, 2 = Monday, ..., 7 = Saturday)
//    18, // Date of the month: 1-31
//     4, // Month: 1-12
//    25  // Year: 0-99 (0 = 2000, 1 = 2001, ..., 99 = 2099)
//  );

  // Initialize RTC module (Run only once after reset the RTC).
  Time_Ctrl 
  (
     0, // Alarm rate: 0-5
     0, // Seconds: 0-59
     0, // Minutes: 0-59
     0, // Hours: 0-23
     0, // Day of the week: 1-7 (1 = Sunday, 2 = Monday, ..., 7 = Saturday), or Date of the month: 1-31
     0  // Select: 1 = day of week, 0 = date of month
  );   

  // Initially retrieve the time values from the RTC module
  Time_Get(&time_get_data);

   // Clear all alarms in the EEPROM module
  //  for (int i = 0; i < ALARM_SLOT_NUM; i++)
  //  {
  //    Alarm_Clear(i);
  //    alarm_slot_ptr = 0;
  //    Alarm_Slot_Pointer_Set();
  //  }

   // Store values of a single alarm to the next available address on the EEPROM module
   //    void Alarm_Set (uint8_t sec, uint8_t min, uint8_t hour, uint8_t dow_dom, ALARM_DY_DT_MODE dy_dt, bool on_off, uint8_t slot)
  //  Alarm_Set
  //  (
  //    00,    // Seconds: 0-59
  //    10,    // Minutes: 0-59
  //    23,    // Hours: 0-23
  //     9,    // Day of the week: 1-7 (1 = Sunday, 2 = Monday, ..., 7 = Saturday), or Date of the month: 1-31, or not used: 0
  //     2,    // Select: 0 = date of month, 1 = day of week, 2 = not used
  //    true,  // true = ON, false = OFF
  //     1     // Slot number of the alarm in the EEPROM module (0-9)
  //  );
  //  Alarm_Get(1, &alarm_get_data[1]);
  //  alarm_slot_ptr = 1;


  // Initially retrieve the alarm slot pointer data from the EEPROM module
  Alarm_Slot_Pointer_Get();

  // Initially retrieve the alarm values from the EEPROM module and send to system memory
  for (int i = 0; i < alarm_slot_ptr; i++)
  {
    Alarm_Get(i, &alarm_get_data[i]);
  }

  // Set the initial system parameters to current time values and default settings for convenience
 

  // Initialize the UART module to receive data
  //    HAL_UART_Receive_IT(UART_HandleTypeDef *huart, uint8_t *pData, uint16_t Size);
  HAL_UART_Receive_IT(&huart1, uart_rx_data, 7);

  // Initialize the ADC module to monitor battery voltage
  //    HAL_ADC_Start_IT(ADC_HandleTypeDef *hadc);
  HAL_ADC_Start_IT(&hadc1);
  void toggle_alarm_buzzer()
  {
	  HAL_GPIO_TogglePin(BUZZER_GPIO_Port, BUZZER_Pin);
  }
  /* USER CODE END 2 */

  /* Infinite loop */
  /* USER CODE BEGIN WHILE */
  while (1)
  {
    
    /* USER CODE END WHILE */

    /* USER CODE BEGIN 3 */
    // while ((button0.int_flag || button1.int_flag || button2.int_flag || button3.int_flag || button4.int_flag)
    // ||     (button0.state == BUTTON_PRESSED || button1.state == BUTTON_PRESSED || button2.state == BUTTON_PRESSED || button3.state == BUTTON_PRESSED || button4.state == BUTTON_PRESSED)
    // ||     (button0.state == BUTTON_WAITING || button1.state == BUTTON_WAITING || button2.state == BUTTON_WAITING || button3.state == BUTTON_WAITING || button4.state == BUTTON_WAITING)
    // ||     ((button0.state == BUTTON_RELEASED || button1.state == BUTTON_RELEASED || button2.state == BUTTON_RELEASED || button3.state == BUTTON_RELEASED || button4.state == BUTTON_RELEASED)
    // &&     (button0.int_flag || button1.int_flag || button2.int_flag || button3.int_flag || button4.int_flag)))
    while ((button0.int_flag || button1.int_flag || button2.int_flag || button3.int_flag || button4.int_flag))
    {
      Button_Handle();
    }
    // TIME_DATA time_get;
    

    // Check if the RTC Interrupt Flag is set (RTC Interrupt Flag) on PB4 (Activated every second)
    if (rtc_int_flag)
    {

      // Retrieve the time values from the RTC module
      Time_Get(&time_get_data);
      Update_alarm_data();

      // Check the alarms
      //   void Alarm_Check (volatile TIME_DATA *time_get_data)
      Alarm_Check(&time_get_data);

      // Reset the RTC Interrupt Flag
      rtc_int_flag = false;

      // Toggle the debug RTC interrupt flag for debugging purposes
      debug_rtc_int = !debug_rtc_int;

      if(system_state.mode == DEFAULT_MODE)
      {   
        default_mode(&flag_sSystem_mode, &time_get_data, battery_percentage);
      }

      if ((button0.press_flag || button1.press_flag|| button2.press_flag || button3.press_flag || button4.press_flag))
      {
        // time_get = (TIME_DATA) time_get_data;
        // Default mode
        if(system_state.mode == DEFAULT_MODE)
        {   
          default_mode(&flag_sSystem_mode, &time_get_data, battery_percentage);
          button0.press_flag = 0;
          button1.press_flag = 0;
          button2.press_flag = 0;
          button3.press_flag = 0;
          button4.press_flag = 0;
        }
        // System setup mode
        else if(system_state.mode == SYSTEM_OPTIONS_MODE)
        {   
          // system_setup_mode (FLAG_SYSTEM *flag_set_up,  CONTROL_SCREEN *Control_screen);
          system_setup_mode (&flag_sSystem_mode,  &system_state, battery_percentage);
          button0.press_flag = 0;
          button1.press_flag = 0;
          button2.press_flag = 0;
          button3.press_flag = 0;
          button4.press_flag = 0;
        }
        // Alarm_set_up mode
        else if(system_state.mode == ALARM_SETUP_MODE)
        {   
          //alarm_setup_mode(FLAG_SYSTEM *flag_alarm_set_up_mode, CONTROL_SCREEN *Control_screen, SYSTEM_PARAM_DATA_ALARM_VIEW_MODE *alarm_view_mode);
          alarm_setup_mode(&flag_sSystem_mode, &system_state, &alarm_setup_data, battery_percentage);
          button0.press_flag = 0;
          button1.press_flag = 0;
          button2.press_flag = 0;
          button3.press_flag = 0;
          button4.press_flag = 0;
        }
        // alarm view mode
        else if(system_state.mode == ALARM_VIEW_MODE)
        {   
          //alarm_view_mode (FLAG_SYSTEM *flag_alarm_view_mode, CONTROL_SCREEN *Control_screen, uint8_t *count_view, uint8_t *count_select, SYSTEM_PARAM_DATA_ALARM_VIEW_MODE *alarm_view_mode);
          alarm_view_mode (&flag_sSystem_mode, &system_state, &sParam_data_alarm_view_mode, battery_percentage);
          button0.press_flag = 0;
          button1.press_flag = 0;
          button2.press_flag = 0;
          button3.press_flag = 0;
          button4.press_flag = 0;
        }
        //alarm time set up mode
        else if(system_state.mode == TIME_SETUP_MODE)
        {   
          time_setup_mode(&flag_sSystem_mode, &system_state, &time_setup_data, battery_percentage);
          button0.press_flag = 0;
          button1.press_flag = 0;
          button2.press_flag = 0;
          button3.press_flag = 0;
          button4.press_flag = 0;
        }
      }
      toggle_alarm_buzzer();

       // Check if the alarm is active
      if (alarm_active_flag)
      {
      // Call the alarm ringing function
        Alarm_Ring();

      // Call the system alarm active mode handler to track if any button is pressed
        System_Alarm_Active_Mode_Handle(&button0);
      }
    }

    // Check if the ADC interrupt flag is set (ADC Valid Flag)
      if (adc_valid_flag)
	  {
      // Re-enable the ADC interrupt to continue monitoring ADC values
      HAL_ADC_Start_IT(&hadc1);
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

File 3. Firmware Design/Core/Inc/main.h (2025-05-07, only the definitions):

#define BUSY_Pin GPIO_PIN_0
#define BUSY_GPIO_Port GPIOA
#define RST_Pin GPIO_PIN_1
#define RST_GPIO_Port GPIOA
#define DC_Pin GPIO_PIN_2
#define DC_GPIO_Port GPIOA
#define SPI_CS_Pin GPIO_PIN_3
#define SPI_CS_GPIO_Port GPIOA
#define SCK_Pin GPIO_PIN_5
#define SCK_GPIO_Port GPIOA
#define DIN_Pin GPIO_PIN_7
#define DIN_GPIO_Port GPIOA
#define BUZZER_Pin GPIO_PIN_0
#define BUZZER_GPIO_Port GPIOB
#define PWR_Pin GPIO_PIN_1
#define PWR_GPIO_Port GPIOB
#define BUTTON0_IN12_Pin GPIO_PIN_12
#define BUTTON0_IN12_GPIO_Port GPIOB
#define BUTTON0_IN12_EXTI_IRQn EXTI15_10_IRQn
#define BUTTON1_IN13_Pin GPIO_PIN_13
#define BUTTON1_IN13_GPIO_Port GPIOB
#define BUTTON1_IN13_EXTI_IRQn EXTI15_10_IRQn
#define BUTTON2_IN14_Pin GPIO_PIN_14
#define BUTTON2_IN14_GPIO_Port GPIOB
#define BUTTON2_IN14_EXTI_IRQn EXTI15_10_IRQn
#define BUTTON3_IN15_Pin GPIO_PIN_15
#define BUTTON3_IN15_GPIO_Port GPIOB
#define BUTTON3_IN15_EXTI_IRQn EXTI15_10_IRQn
#define BUTTON4_IN8_Pin GPIO_PIN_8
#define BUTTON4_IN8_GPIO_Port GPIOA
#define BUTTON4_IN8_EXTI_IRQn EXTI9_5_IRQn
#define RTC_IN5_Pin GPIO_PIN_5
#define RTC_IN5_GPIO_Port GPIOB
#define RTC_IN5_EXTI_IRQn EXTI9_5_IRQn

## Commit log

2025-02-13 Project Requirements
    [Requirements.xlsx]
2025-02-17 Updated Requirements
    [Requirements.xlsx]
2025-03-17 Update Requirements
    [Requirements.xlsx]
2025-03-17 Update Documents
    [Components.xlsx, Requirements.xlsx]
2025-03-17 Add PCB folder
2025-03-17 Update Alarm Interrupt (Unfinished)
2025-03-18 Update Alarm Interrupt Every Second (Finished)
2025-03-19 Update I2C2
2025-04-02 Change Folders' Name
    [Components.xlsx, Requirements.xlsx]
2025-04-02 Update Schematic & PCB Designs
    [01_Cover_Page.SchDoc, 02_Block_Diagram.SchDoc, 03_Power_Spply.SchDoc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]
2025-04-02 Update Firmware: Pin Declarations & File Organization
2025-04-02 Merge code lines for ADC and UART interface
    - Chang some variables' name to match a naming convention
    - Fix array pointer error (function HAL_UART_Receive_IT in main and in while loop in main)
    [main.c]
2025-04-04 update demo e-ink
    [04_MCU.SchDoc, 05_Uart_Bluetooth.SchDoc]
2025-04-05 Update Program: Button Interrupt Handler
    [ES_Project_Digital-Clock Debug.cfg]
2025-04-05 Update: Button Interrupt Handler
2025-04-10 Optimization: Alarm Handler, Button Handler, Interface Handler (for debugging only)
    SUMMARY OF CHANGES
    1. DEBUG_ALARM_SELECT: Structure to track the values being selected for modification
    -> volatile uint8_t debug_button_counter[5]: Track if the button is pressed or not
    2. Variable names modification:
    - time_get_data
    - alarm_get_data
    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
2025-04-10 Separate, Optimize Button Handle Function; Add a Button Hold State for Convenience
2025-04-12 UI-UX update
    - Optimize Button Debouncer
    - Add UI-UX features with button short and long press to: select mode, set time, set alarm
    - Unfinish: alarm view mode, alarm activate mode, system setting mode
    [main.c]
2025-04-15 Optimization: System Mode Handlers; Alarm data & Alarm Functions
    - Separate System Mode Handlers;
    - Replace encoded alarm data by decoded one, Alarm_Get function decodes data by its own;
    - Enhance accuracy of Alarm_Check function;
    - Add alarm slot pointer and its handler (pointer data saved in EEPROM)
    - Add a clear all alarm option (button 4 long press) in Alarm Set Handler
    [ES_Project_Digital-Clock.ioc, main.c]
2025-04-18 update code to combine
    [code_e_ink Debug.cfg]
2025-04-18 Revert "E ink display"
    [04_MCU.SchDoc, 05_Uart_Bluetooth.SchDoc, code_e_ink Debug.cfg]
2025-04-18 update the e-ink-displat
    [code_e_ink Debug.cfg]
2025-04-18 Update I-O Config: SPI, GPIO for E-Ink Display
2025-04-18 Change Pin: PA0 - EXTI0 for BUSY pin
2025-05-03 Fixed: Alarm_Set, Alarm_Set, Alarm_Slot_Pointer_Set, Alarm_Slot_Pointer_Get
    - Alarm_Get: Delay 1ms -> 5ms
    - Ở hàm HAL_I2C_Mem_Write: MemAddSize 1 -> 2
    [ES_Project_Digital-Clock.ioc, main.c, main.h]
2025-05-07 Revert "."
    This reverts commit 06d5eddf3b4cb744d82802293c44e9e011c34823.
    [main.c]
2025-05-07 update final
    [01_Cover_Page.SchDoc, 02_Block_Diagram.SchDoc, 03_Power_Spply.SchDoc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]
2025-05-07 Final refine
    [01_Cover_Page.SchDoc, 02_Block_Diagram.SchDoc, 03_Power_Spply.SchDoc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]
2025-05-07 Revert "Final refine"
    This reverts commit a4b0fc81d4a014b9263aa20eb7bc8bbb2eb78758.
    [ES_Project_Digital-Clock Debug.cfg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]
2025-05-07 Update Hardware Design
    [01_Cover_Page.SchDoc, 02_Block_Diagram.SchDoc, 03_Power_Spply.SchDoc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]
2025-05-07 Update Firmware
    [3. Firmware.cfg, ES_Project_Digital-Clock Debug.cfg]

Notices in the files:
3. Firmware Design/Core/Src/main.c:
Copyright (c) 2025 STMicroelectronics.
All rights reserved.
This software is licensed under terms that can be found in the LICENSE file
